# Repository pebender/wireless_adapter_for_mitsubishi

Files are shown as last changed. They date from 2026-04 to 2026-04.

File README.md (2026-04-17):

# A Wireless Adapter for a Mitsubishi Heat Pump Indoor Unit

This project is neither associated with nor endorsed by Mitsubishi Electric. By using this project, you may void your warranty or break your heat pump.

## The Wireless Adapter

The wireless adapter is a device for connecting an indoor unit of [our Mitsubishi Electric heat pump system](./docs/requirements.md#existing-system) to [our home automation system](./docs/background/automation.md). The wireless adapter is similar to [Mitsubishi Electric's PAC-USWHS002-WF-2 Wireless Interface 2](https://www.mitsubishipro.com/products/PAC-USWHS002-WF-2), except the wireless adapter is Open Source and doesn't depend on a cloud service.

The wireless adapter has three distinct parts

- the Open Source [hardware](./docs/hardware.md),
- the Open Source [enclosure](./docs/enclosure.md) and
- the Open Source [firmware](./docs/firmware.md).

### The Wireless Adapter Hardware

The [hardware](./docs/hardware.md) is likely both overly and poorly designed. Relative to many other people's designs, my design pays (more) attention to safety, including correct logic levels, safe power consumption and transient voltage suppression.

The hardware is a two-layer printed circuit board assembly (PCBA). I did the design and layout using the Open Source PCB design suite [KiCad](https://www.kicad.org). In addition, I did the step down power supply design using [Texas Instrument's WEBENCH&reg; Power Designer](https://webench.ti.com/power-designer/). I paid [JLCPCB](https://jlcpcb.com) to fabricate and assemble the hardware. I licensed the hardware design and layout under the [MIT license](./LICENSE.txt).

### The Wireless Adapter Enclosure

The [enclosure](./docs/enclosure.md) is likely overly conservative. I had no experience designing 3D printed enclosures, and I wanted to be sure the enclosure wasn't too fragile.

I did the enclosure design using the Open Source 3D parametric modeler [FreeCAD](https://www.freecad.org). I paid JLCPCB to 3D print the enclosure. I licensed the enclosure design under the MIT license.

### The Wireless Adapter Firmware

I contributed nothing to the [firmware](./docs/firmware.md). I built it from the Open Source [ESPHome](https://esphome.io) and the Open Source [mUART Project](https://muart-group.github.io)'s [mitsubishi_itp](https://github.com/muart-group/esphome-components) ESPHome component,

## The Motivation

I undertook this project because

- I needed a project,
- I wanted to learn what it takes to develop hardware today,
- I wanted to learn what it takes to develop enclosures, and
- I wasn't satisfied with our current solution for connecting the indoor units of our Mitsubishi Electric heat pump system to our home automation system. It depends on two [Honeywell THM6000R7001 RedLINK&reg; Internet Gateways](https://www.resideo.com/us/en/pro/products/air/thermostats/thermostat-accessories/redlinkr-internet-gateway-with-ethernet-cable-and-power-cord-thm6000r7001-u/) and the [Honeywell Home Total Connect Comfort](https://mytotalconnectcomfort.com) cloud. Because of its reliance on the RedLINK&reg; wireless protocol, it's relatively slow. In addition, because its reliance on the cloud it's relatively unreliable.

I wouldn't have undertaken this project had others not already done the work to connect their Mitsubishi Electric heat pumps to their home automation systems, including

- [Hadley Rich's hacking of his Mitsubishi heat pump)](https://nicegear.nz/blog/hacking-a-mitsubishi-heat-pump-air-conditioner/),
- [SwiCago's HeatPump software](https://github.com/SwiCago/HeatPump),
- [Geoff Davis (esphome-mitsubishiheatpump software)](https://github.com/geoffdavis/esphome-mitsubishiheatpump), and
- [the mUART project's software](https://muart-group.github.io).

In addition, I wouldn't have undertaken this project without the knowledge and confidence I gained as

- a high school student in [John McCollum](https://www.eetimes.com/john-mccollum-hs-teacher-taught-electronics-with-love/)'s electronics class at [Homestead High School](https://en.wikipedia.org/wiki/Homestead_High_School_(California)),
- a hardware intern at [NCR](https://www.ncr.com),
- a PhD student under [Jack Wolf](https://en.wikipedia.org/wiki/Jack_Wolf) at the [University of California San Diego (UCSD)](https://ucsd.edu), and
- a 20+ year employee at [Qualcomm](https://www.qualcomm.com).

Finally, I wouldn't have undertaken this project had an existing design contained

- a level shifter for the UART signals,
- a power module designed to meet the required efficiency and the EMI standards, and
- a reasonable level of Transient Voltage Suppression (TVS).

My [background](./docs/background.md) provides more insight into why I undertook this project.

## The Evolution

I didn't design the hardware and the enclosure as a unified project. Initially, I designed the hardware with the intent of using an off-the-shelf enclosure. So, I designed the hardware to fit in the off-the-shelf enclosure. However, I ran into problems mounting the hardware in the off-the-shelf enclosure as well as cutting the necessary openings in the off-the-shelf enclosure. So, I decided to make a custom enclosure. However, I already had the hardware fabricated and assembled. Therefore, I designed the enclosure around the existing hardware. Had I designed them together, both the hardware and the enclosure would have been different.

## References

[References](./docs/references.md)

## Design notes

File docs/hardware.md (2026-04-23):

# Wireless Adapter Hardware

I designed the wireless adapter hardware to meet [these requirements](./requirements.md).

The current design is the same circuit design and PCB layout as the design I had fabricated except

- I changed the value of capacitor C2 from 1μF to 0.1μF,
- I removed instances of different signals sharing one ground via from the PCB,
- I improved the USB data lines differential routing,
- I removed the wall mounting passthrough hole from the PCB,
- I added the name and revision to the PCB,
- I switched from a hierarchical schematic to a flat schematic, and
- I updated from KiCad 9.0.x to KiCad 10.0.x.

## Architecture

The high level block diagram below shows basic functions of the wireless adapter.

The [USB connector](./hardware/development.md#usb-connector) (along with the [reset and boot switches](./hardware/development.md#switches)) eases development.

The [IU connector](./hardware/connectors.md#the-wireless-adapters-iu-connector) and [WR connector](./hardware/connectors.md#the-wireless-adapters-wr-connector) connect to the indoor unit of a Mitsubishi Electric heat pump and the wireless receiver of a Mitsubishi Electric controller kit respectively

The [power multiplexer](./hardware/power.md#power-multiplexer) switches between the 5V power provided through the USB connector and the 12.7V power provided through the IU connector, with priority given to the IU connector's 12.7V power when present. This allows the USB connector to power the System on a Chip (SoC) during development.

The [voltage regulator](./hardware/power.md#33v-output-switching-voltage-regulator) converts the power from the output of the power multiplexer to the 3.3V needed to power the SoC as well as power the SoC side of the level shifter.

The [level shifter](./hardware/connectors.md#level-shifter) converts the UART signals between the 3.3V signals expected by the SoC and the 5V signals expected by the indoor unit (connected via the IU connector) and the wireless receiver (connected via the WR connector).

The SoC provides the Wi-Fi, Thread and Bluetooth LE interfaces to the indoor unit and the wireless receiver.

```mermaid
block
columns 7

USB["USB Connector"]
space:3
IU["IU Connector"]
space
WR["WR Connector"]

space:7

space:2
MULTIPLEXER["Power Multiplexer"]
space:1

block:LS["Level Shifter"]:3
    columns 3
    LS_IU_5V["TX/RX @5V"]
    LS_5V["5V"]
    LS_WR_5V["RX/TX @5V"]
    space:3
    LS_IU_3V3["TX/RX @3.3V"]
    LS_3V3["3.3V"]
    LS_WR_3V3["RX/TX @3.3V"]
end

space:7

space:2
REGULATOR["Voltage Regulator"]
space:4

space:7

block:SOC["System on a Chip"]:7
  columns 7
  USB_JTAG["USB Serial / JTAG"]
  space:1
  SOC_3V3["3.3V"]
  space:1
  UART_0["UART 0"]
  space:1
  UART_1["UART 1"]
  space:7
  CPU["CPU"]
  space:1
  WIFI["Wi-Fi"]
  space:1
  THREAD["Thread"]
  space:1
  BLE["Bluetooth LE"]
end

USB -- "5V" --> MULTIPLEXER
USB -- "D+/D-" --> USB_JTAG
USB_JTAG -- "D+/D-" --> USB

MULTIPLEXER --> REGULATOR
IU -- "12.7V/5V/GND" --> WR
IU -- "12.7V" --> MULTIPLEXER

IU -- "5V" --> LS_5V
IU -- "UART TX/RX" --> LS_IU_5V
LS_IU_5V -- "UART TX/RX" --> IU
WR -- "UART RX/TX" --> LS_WR_5V
LS_WR_5V -- "UART RX/TX" --> WR

LS_IU_5V --> LS_IU_3V3
LS_IU_3V3 --> LS_IU_5V
LS_WR_5V --> LS_WR_3V3
LS_WR_3V3 --> LS_WR_5V

REGULATOR -- "3.3V" --> LS_3V3
LS_IU_3V3 -- "UART TX/RX" --> UART_0
UART_0 -- "UART TX/RX" --> LS_IU_3V3
LS_WR_3V3 -- "UART RX/TX" --> UART_1
UART_1 -- "UART RX/TX" --> LS_WR_3V3

REGULATOR -- "3.3V" --> SOC_3V3
```

# Fabrication and Assembly

This is the first time that I have had a PCBA fabricated and assembled.

I chose [JLCPCB](https://jlcpcb.com) because they are a inexpensive, one-stop shop. They

- provide [parts](https://jlcpcb.com/parts),
- provide [PCB fabrication](https://jlcpcb.com/pcb-fabrication/fr4-pcb),
- provide [PCB assembly](https://jlcpcb.com/pcb-assembly),
- are reasonably priced, and
- are reasonably fast.

Because I chose JLCPCB, I made sure the parts I used are available from [JLCPCB parts](https://hlcpcb.com/parts). When possible, I chose resistors, capacitors and diodes that were available as basic or promotional extended parts because they are cheaper during PCB assembly. In addition, I chose parts that support surface mounted technology (SMT) rather than through hole technology (THT) because they are cheaper during assembly. The one exception is the JST S05B-PASK-2(LF)(SN) connector used for the IU connector and WR connector because through hole connectors tend to be more securely attached than surface mount connectors.

I made two versions of the PCBA. The first version was the test version. The second version was the "production" version. The first version worked but the USB-C connector was poorly placed. The second version was similar to the first version except the switches and ESD diodes were replaced with basic or promotional extended parts, the LEDs were removed, and the layout was changed.

## The Completed Design

### The Parts List

 The PCBA contains the parts

- System on a Chip: [Espressif ESP32-C6-WROOM-1-N8](./hardware/soc.md) (U1)
- Level Shifter: [Texas Instruments TXS0104EPW](./hardware/connectors.md#level-shifter) (U2)
- Power Multiplexer: [Texas Instruments TPS2121RUX](./hardware/power.md#power-multiplexer) (U7)
- Power Module: [Texas Instruments TPSM5601R5HRDA](./hardware/power.md#33v-output-switching-voltage-regulator) (U8)
- TVS Devices: [Texas Instruments TVS1400DRV](./hardware/connectors.md#power-pin-voltage-surge-protection) (U3, U5) and [Texas Instruments TVS0500DRV](./hardware/connectors.md#power-pin-voltage-surge-protection) (U4, U6)
- ESD Diodes: [R+O H5VL10B](./hardware/connectors.md#signal-pin-voltage-surge-protection) (D1-D7)
- USB Connector: [G-Switch GT-USB-7010ASV](./hardware/development.md#usb-connector) (J3)
- IU Connector: [JST S05B-PASK-2](./hardware/connectors.md#connectors) (J1)
- WR Connector: [JST S05B-PASK-2](./hardware/connectors.md#connectors) (J2)
- Switches: [XunPu TS-1088-AR02016](./hardware/development.md#switches) (S1, S2)
- Capacitors: [Samsung Electro-Mechanics capacitors](./hardware/passive.md#capacitors) (C1-C15)
- Resistors: [Uni-royal thick film 0402/0603/0805/1206/1210/1812/2010/2512 series resistors](./hardware/passive.md#resistors) (R1-R13)
- Inductor: [Murata DFE201610E-R47M=P2 inductor](./hardware/passive.md#inductors) (L1)

When selecting parts, I selected

- Espressif parts because I am familiar Espressif's development tools,
- Texas Instruments parts because I am familiar with Texas Instruments' design documentation and tools, and
- JLCPCB basic and promotional extended parts because they are less expensive during assembly.

### The Schematic

schematic

### The PCBA

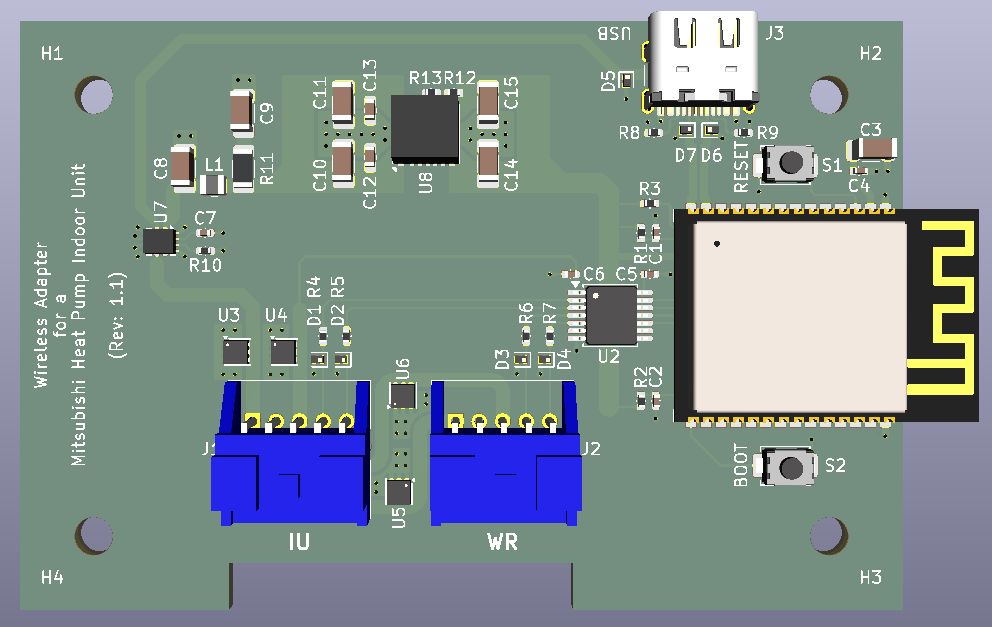
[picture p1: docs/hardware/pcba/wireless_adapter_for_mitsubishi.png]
PCBA


The completed PCBA is a two-layer, rigid PCBA. The bottom layer contains a ground plane. The top layer contains ground pours, the power pours, the power traces, the signal traces and the parts.

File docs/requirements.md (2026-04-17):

# Wireless Adapter Requirements

## Goal

The goal of this project is to create an Open Source wireless adapter for connecting the indoor units of our Mitsubishi Electric heat pump system to our [Home Assistant](https://www.home-assistant.io) centered home automation system without depending on the cloud.

## Existing System

Our Mitsubishi Electric heat pump system consists of eight indoor units

- MSZ-GL06NA-U1 (study),
- MSZ-GL09NA-U1 (office),
- MSZ-GL09NA-U1 (guest bedroom),
- MSZ-GL09NA-U1 (back bedroom),
- MSZ-GL15NA-U1 (family room),
- MSZ-GL18NA-U1 (kitchen),
- MSZ-GL18NA-U1 (living room),
- MSZ-GL18NA-U1 (master bedroom),

connected to three outdoor units

- MUZ-GL15NA-U1 (family room),
- MXZ-4C36NA2-U1 (kitchen, study, master bedroom), and
- MXZ-5C42NA2-U1 (living room, office, guest bedroom, back bedroom).

Each indoor unit is connected to a [Mitsubishi Electric MHK1 controller kit](https://www.mitsubishipro.com/products/MHK1), consisting of a MIFH1 wireless receiver and a MRCH1 remote controller.

In addition to being paired with its MRCH1 remote controller, the MIFH1 wireless receiver connected to each indoor unit is paired with one of two [Honeywell THM6000R7001 RedLINK&reg; Internet Gateways](https://www.resideo.com/us/en/pro/products/air/thermostats/thermostat-accessories/redlinkr-internet-gateway-with-ethernet-cable-and-power-cord-thm6000r7001-u/). The THM6000R7001 internet gateways enable control of the indoor units from our phones and our home automation system. Unfortunately, they have two shortcomings. First, they have a slow response time because the RedLINK&reg; wireless protocol between the THM6000R7001 internet gateway and the MIFH1 wireless receiver is slow. Second, they can be unreliable because all their traffic is sent through the [Honeywell Home Total Connect Comfort](https://mytotalconnectcomfort.com) cloud. It's the THM6000R7001 internet gateways that this project will replace.

## Top Level Requirements

### Freedom Requirements

1. The wireless adapter hardware design must be Open Source.
    - The hardware components (e.g. the SoC) need not be Open Source.
2. The wireless adapter enclosure design must be Open Source
3. The wireless adapter firmware must be Open Source.
    - This prevents the owner of the wireless adapter from being subject to the whims of the firmware provider.
4. The wireless adapter must not require a cloud.
    - This prevents the owner of the wireless adapter from being subject to the whims of the cloud provider. For example, I was burned by a Genie Aladdin Connect when they changed their cloud API effectively blocking Home Assistant from using the cloud API.
5. The wireless adapter development tools must be Open Source.
    - This makes it easier to view and modify the wireless adapter design because the development tools are available without monetary or other restrictions.

### Connected Hardware Requirements

1. The wireless adapter must support the indoor units
    - the Mitsubishi Electric MSZ-GL06NA-U1,
    - the Mitsubishi Electric MSZ-GL09NA-U1,
    - the Mitsubishi Electric MSZ-GL15NA-U1 and
    - the Mitsubishi Electric MSZ-GL18NA-U1.
2. The wireless adapter must support the MIFH1 wireless receiver.
3. The wireless adapter must support the MIFH2 wireless receiver (aka MIFH2 receiver).
4. The wireless adapter must allow normal operation of the Mitsubishi Electric MHK1 remote controller kit.
5. The wireless adapter must allow normal operation of the Mitsubishi Electric MHK2 remote controller kit.

### Radios

1. The wireless adapter must support a wireless connection using 2.4 [Wi-Fi&reg;](https://www.wi-fi.org).
    - ESPHome supports Wi-Fi.
    - Matter supports Wi-Fi.
2. The wireless adapter must support a wireless connection using [Thread&reg;](https://threadgroup.org) 1.4.
    - ESPHome supports Thread.
    - Matter supports Thread.
    - A Thread radio at each indoor unit should form a good backbone for a Thread network.
3. The wireless adapter must support [Bluetooth&reg;](https://www.bluetooth.com/) LE.
    - The Matter provisioning protocol relies on Bluetooth LE.

### Firmware

1. The wireless adapter hardware must support [ESPHome](https://esphome.io) firmware.
2. The wireless adapter hardware must support ESPHome over Wi-Fi.
3. The wireless adapter hardware must support ESPHome over Thread 1.4.
4. The wireless adapter hardware running ESPHome firmware must support the [Home Assistant](https://www.home-assistant.io) home automation system.
5. The wireless adapter hardware may support [Matter](https://csa-iot.org/all-solutions/matter/) firmware.

### Firmware Development

1. The wireless adapter must provide a USB-C connector.
    - The move has been toward the USB-C connector and away from other types of USB connectors.
2. The wireless adapter must support wireless adapter firmware download, debug and recovery over USB.
3. The wireless adapter must support being powered over USB.
4. The wireless adapter should provide transient voltage suppression (TVS) or electrostatic discharge (ESD) protection on the USB's VBUS, D+ and D- pins.

### IU Connector

1. The wireless adapter must provide a connector that is physically and electrically the same as the indoor unit's CN105 connector except that the UART RX and UART TX pins are reversed.
    - See [the IU connector](#the-iu-connector).
2. The wireless adapter must provide transient voltage suppression (TVS) for the connector's 12.7V and 5V pins.
3. The wireless adapter must provide electrostatic discharge (ESD) protection for the connector's UART RX and UART TX pins.
4. The wireless adapter must provide current limiting resistors for the connector's UART RX and UART TX pins.
5. The wireless adapter must control the indoor unit through a wired connection between connector to the indoor unit's CN105 connector.

### WR Connector

1. The wireless adapter must provide a connector that is physically and electrically the same as the indoor unit's CN105 connector.
    - See [the WR connector](#the-wr-connector).
2. The wireless adapter must provide transient voltage suppression (TVS) for the connector's 12.7V and 5V pins.
3. The wireless adapter must provide electrostatic discharge (ESD) protection for the connector's UART RX and UART TX pins.
4. The wireless adapter must provide current limiting resistors for the connectors UART RX and UART TX pins.

### Power

1. The wireless adapter must require no other power source than the indoor unit's CN105 connector.
2. The wireless adapter must be powered by the 12.7V pin of the indoor unit's CN105 connector.
    - See [Maximum Allowed Power Consumption](#maximum-allowed-power-consumption).
3. The wireless adapter must draw no more than 2W from the 12.7V pin of the indoor unit's CN105 connector.
    - See [Maximum Allowed Power Consumption](#maximum-allowed-power-consumption).
4. The wireless adapter may power the 5V side of the level shifter using the 5V pin of the indoor unit's CN105 connector.

## Maximum Allowed Power Consumption

I found no documentation covering the power supplied by the indoor unit's CN105 connector.

However, the wireless adapter is functionally the same as the [Mitsubishi Electric's PAC-USWHS002-WF-2 Wireless Interface 2](https://www.mitsubishipro.com/products/PAC-USWHS002-WF-2) except that the PAC-USWHS002-WF-2 requires a cloud and is not Open Source. Therefore, using the PAC-USWHS002-WF-2, I have been able to determine a power the wireless adapter can consume while still allowing my indoor unit to safely power the wireless adapter and the MIFH1/MIFH2 wireless receiver.

The [PAC-USWHS002-WF-2 Installation/Instruction Manual from 2021](https://s3.amazonaws.com/enter.mehvac.com/DAMRoot/Original/10006/PAC-USWHS002-WF-2_Install_Manual.pdf) states that the PAC-USWHS002-WF-2 consumes a maximum of 2W at 12.7V. So, a device that consumes no more than 2W from the CN105's 12.7V pin could be powered by any indoor unit compatible with the PAC-USWHS002-WF-2.

The [PAC-USWHS002-WF-2 Compatibility Submittal from 2021](https://s3.amazonaws.com/enter.mehvac.com/DAMRoot/Original/10009/M_Submittal_PAC-USWHS002-WF-2.pdf) states that simultaneous use of the PAC-USWHS002-WF-2 and the MIFH1/MIFH2 wireless receiver is only compatible with a subset of indoor units individually compatible with the PAC-USWHS002-WF-2 and the MIFH1/MIFH2 wireless receiver due to power requirements. My indoor units are compatible with simultaneous use of the PAC-USWHS002-WF-2 and the MIFH1 wireless receiver. Therefore, my indoor units could simultaneously power the MIFH1 wireless receiver and a device that consumes no more than 2W from the CN105 connector's 12.7V pin.

I have found no information showing that any of my indoor units could simultaneously power the wireless adapter and the MIFH1 wireless receiver were the wireless adapter to consume more than 2W from the CN105 connector's 12.7V pin. Therefore, the power requirement is that the device must consume no more then 2W of power from the CN105 connector's 12.7V pin.

## The WR Connector

[Airzone](https://www.airzonecontrol.com/) enables connection of both its [AZAI6WSCMEL Aidoo WiFi controller](https://www.airzonecontrol.com/na/en/support/technical-details/aidoo-wi-fi-mitsubishi-electric/) and a MIFH1/MIFH2 wireless receiver to connect to an indoor unit using its separate [AZX6ACCSPLMEL CN105 port splitter](https://www.airzonecontrol.com/na/en/support/technical-details/CN105-port-splitter-mitsubishi-electric/). However, [Mitsubishi Electric's PAC-USWHS002-WF-2 Wireless Interface 2](https://www.mitsubishipro.com/products/PAC-USWHS002-WF-2) integrates a port for connecting a MIFH1/MIFH2 wireless receiver rather than relying on a separate device. In addition, the [mUART Project](https://muart-group.github.io)'s [mitsubishi_itp](https://github.com/muart-group/esphome-components/tree/dev/components/mitsubishi_itp) ESPHome component expects the MIFH1/MIFH2 wireless receiver to connect to the same hardware on which it is running.

Therefore, the wireless adapter must provide a connector for connecting a MIFH1/MIFH2 wireless receiver.

Since both the MIFH1 wireless receiver and the MIFH2 wireless receiver come with a cable with a connector that is expected to be plugged into the indoor unit's CN105 connector, the wireless adapter must provide a connector that is physically and electrically the same as the indoor unit's CN105 connector, with the exceptions that there may be less power available on the 12.7V and 5V pins.

 Therefore, the wireless adapter must provide a connector that is physically and electrically the same as the indoor unit's CN105 connector.

## The IU Connector

The wireless adapters's indoor unit (IU) connector could be either the same as or different from the WR connector.

Advantages of the IR and WR connectors being the same include

- fewer component variants in the design, and
- pre-made PAP-05V-S cables are available.

Disadvantages of the IR and WR connectors being the same include

- installer could confuse the two connectors.

If the wireless adapter is connected to the indoor unit using a rollover cable (a.k.a. same direction cable), then the IU and WR connectors will both have 12.7V, GND and 5V on pins 1, 2 and 3 respectively, and the IU connector will have its UART RX and TX pins reversed relative to the WR connector.

This can be addressed either by using a cable that swaps the the UART RX and TX pins or by protecting the UART pins when RX is connected to RX and TX is connected to TX.

Protocol agnostic straight-through cables (a.k.a. reverse direction cables) and rollover cables are available for a wide variety of connectors. However, crossover cables (cables that reverse the communication protocols RX and TX pins) are only available for common protocols with normalized (standardized) connectors and pin-outs (e.g. cables for ethernet over twisted-pair), which this is not. In addition, the current-limiting resistors on the UART pins of both connectors would protect the wireless adapter, the indoor unit and the MIFH1/MIFH2 wireless receiver from potential damage caused by the UART RX and TX pins being crossed when the user confuses the connectors.

Both Mitsubishi Electric's PAC-USWHS002-WF-2 wireless interface 2 and Airzone's AZX6ACCSPLMEL CN105 port splitter use the same type of connector to connect both the indoor unit and MIFH1/MIFH2 wireless receiver. Both connect to the indoor unit using a rollover cable.

 Therefore, the wireless adapter must provide a connector that is physically and electrically the same as the indoor unit's CN105 connector except that the UART RX and UART TX pins are reversed.

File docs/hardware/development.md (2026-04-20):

# Development

The wireless adapter has circuitry specifically for development. The design for this circuitry follows the design of the [ESP32-C6-DevKitC-1](https://dl.espressif.com/dl/schematics/esp32-c6-devkitc-1-schematics_v1.4.pdf).

## Switches

The wireless adapter has a switch to initiate chip reset and a switch to select the boot method. For the switches, I chose the [XunPu TS-1088-AR02016](https://www.lcsc.com/datasheet/C720477.pdf) because

- they're compact,
- they're in the JLCPCB basic parts type so it's lower cost during PCB assembly.

I used an RC filter to debounce each switch. When the switch is open, the resistor pulls the output high. When the switch is closed, the switch pulls the output low. The time constant of the reset switch's RC filter is ~10x the time constant of the boot switch's RC filter so that on power up the boot switch has time to be pulled high before the reset switch is pulled high.

## USB Connector

The wireless adapter has a 16-pin USB 2.0 Type-C connector providing USB 2.0 connectivity to the ESP32-C6-WROOM-1-N8's USB data lines. The ESP32-C6 supports 12Mbps transfer rate and implements USB serial and JTAG controller. I chose a Type-C connector because the Type-C connector is compact and has become the dominant USB connector. Any 16-pin USB 2.0 Type-C connector should work. I selected the [G-Switch GT-USB-7010ASV](https://www.lcsc.com/datasheet/C2988369.pdf).

## Protection

The wireless adapter has 5V bidirectional ESD diodes on the USB VBUS, D+ and D- lines to provide [ESD protection](./connectors.md#signal-pin-voltage-surge-protection).

## Power Multiplexer

The wireless adapter [multiplexes the 12.7V from the IU connector and the 5V from the USB connector](./power.md#power-multiplexer) so that the wireless adapter remains powered when doing development without the wireless adapter being connected to the indoor unit.

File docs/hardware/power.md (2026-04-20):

# Power

## Overview

The power design uses

- a [Texas Instruments TPS2121RUX](https://www.ti.com/product/TPS2121) power multiplexer to select whether the wireless adapter is powered by the IU connector's 12.7V pin or the USB connector's VBUS pins with priority given to power from the IU connector's 12.7V pin when present,
- a [Texas Instruments TPSM5601R5HRDA](https://www.ti.com/product/TPSM5601R5H) switching power module to convert the multiplexed voltage to 3.3V,
- capacitors at the input and output of the TPSM5601R5HRDA to reduce output voltage ripple caused by the power module's switching nature and the load's variable current demand, and
- a filter before the input capacitors to reduce the conducted EMI caused by the power module's switching nature to a level that meets the CISPR 22 Class B requirements.

In addition, the power design uses power from the IU connector's 5V pin to power the 5V side of the operational connectors' level shifter.

## Power Multiplexer

In order to power the wireless adapter from the IU connector's 12.7V pin during normal operation and from the USB connector's VBUS pins during firmware development, there must be a way to safely and reliably arbitrate between the two potential power sources. To accomplish this, the design uses the [Texas Instruments TPS2121RUX](https://www.ti.com/product/TPS2121) power multiplexer to multiplex the 12.7V supply from the UI connector and the 5V supply from the USB connector so that the wireless adapter is powered by the 12.7V supply from the indoor unit during normal operation and by the 5V supply from the USB host during firmware development. The 12.7V supply from the UI connector takes priority over the 5 supply from the USB connector. This enables firmware development while connected to the indoor unit.

I chose the Texas Instruments TPS2121RUX power multiplexer because it handles up to a 24V input, which is more than the 19.3V limited to by the [surge protection](./connection.md#power-pin-voltage-surge-protection).

### Rejected Power Multiplexer Options

The design could have assumed that the IU connector and the USB connector would never be connected at the same time, which would have eliminated the need for the power multiplexer. However, that would put the indoor unit, the USB host and the wireless adapter at risk. In addition, it would make firmware more difficult Therefore, I did not take this approach.

The design could have used a mechanical solution such as a jumper or a switch to select the power source. However, jumpers can come loose and both jumpers and switches must be put in the correct position by the user. So, a mechanical solution is susceptible to user error. Therefore, I did not take this approach.

The design could have used Schottkey diodes for power ORing. However, the ~0.5V voltage drop across the diode translates to ~4% power loss when being powered by the 12.7V supply, which is significant when the ESP32-C6-WROOM-1 recommendation for a power supply of 1.65W (3.3V @ 500mA) and the device must draw no more than 2W from the 12.7V supply. Therefore, I did not take this approach.

The design could hae used discrete transistors and resistors for power ORing. As the Texas Instruments TPS2121RUX costs ~$1.00 in small quantities, the discrete solution would very likely be cheaper. However, the ASIC requires fewer components and is more likely to work correctly on the first try. Maybe in the next iteration, I will replace the TPS2121RUX with discrete transistors and resistors. But for this iteration, I did not take this approach.

The design could have done power ORing after conversion to 3.3V. Doing this would have allowed the use of the less expensive [Texas Instruments LM66200DRL](https://www.ti.com/product/LM66200). However, ORing after the conversion to 3.3V would have required separate step down converters for the UI connector's 12.7V supply and the USB connector's 5V supply. This would cut into the cost savings from being able to use the less expensive Texas Instruments LM66200DRL, and would have required more wireless adapter area. Therefore, I did not take this approach.

## Step Down Voltage Regulator

### Power Requirements

Per Section 1.3 of [ESP32-C6 Hardware Design Guidelines (dated 2026.03.03)](https://documentation.espressif.com/esp-hardware-design-guidelines/en/latest/esp32c6/esp-hardware-design-guidelines-en-master-esp32c6.pdf) the recommended power supply has a voltage of 3.3V and an output current of no less than 500mA.

Per Section 6.4 of [ESP32-C6-WROOM-1 & ESP32-C6-WROOM-1U Datasheet (version 1.4)](https://www.espressif.com/sites/default/files/documentation/esp32-c6-wroom-1_wroom-1u_datasheet_en.pdf), the maximum current required by the ESP32-C6-WROOM-1-N8 processor and radio is 382mA, which is needed when transmitting the IEEE 802.11b 1Mbps DSSS waveform at full power. This does not include any power required by any non-radio peripherals (e.g., the UARTs and their associated GPIOs) that might be in use. In addition, this does not include any power required by hardware other than the ESP32-C6-WROOM-1-N8 (e.g., the UART level shifter).

Based on information about the Mitsubishi Electric's PAC-USWHS002-WF-2 Wireless Interface 2, the wireless adapter [must not draw more than 2W from indoor unit's 12.7V supply](../requirements.md#maximum-allowed-power-consumption). Therefore, the step down converter that converts 12.7V to 3.3V must be at least 82.5% efficient to meet the 500mA requirement when the indoor unit is powering the wireless adapter.

I have found no information about the maximum power the wireless adapter can draw from the indoor unit's 5V supply.

### Power During Normal Operation

During normal operation, nothing is connected to the USB connector. Therefore, the wireless adapter is powered by the indoor unit through the wireless adapter's IU connector during normal operation.

#### 3.3V

The ESP32-C6-WROOM-1-N8 and the ESP32-C6-WROOM-1-N8 side of level shifter uses 3.3V. The ESP32-C6-WROOM-1-N8's radios use most of the power. 

From the PAC-USWHS002-WF-2's documentation, [I concluded that the PAC-USWHS002-WF-2 is powered by the indoor unit's 12.7V power source](../requirements.md#maximum-allowed-power-consumption). Therefore, I chose to power most of the wireless adapter from the indoor unit's 12.7V power source during normal operation.

From the PAC-USWHS002-WF-2's documentation, [I concluded that the PAC-USWHS002-WF-2 draws no more than 2W from the indoor unit's 12.7 power source](../requirements.md#maximum-allowed-power-consumption). From this, I concluded that it's safe for the wireless adapter to draw up to 2W from the indoor unit's 12.7 power source but it might not be safe to draw more. Therefore, the step down converter that converts 12.7V to 3.3V must be at least 82.5% efficient to meet the ESP32-C6 Hardware Design Guidelines' 500mA requirement.

Since a linear step down regulator that converts from 12.7V to 3.3V would be 26.0% efficient at best, the design uses a switching step down regulator for converting from 12.7V to 3.3V.

#### 5V

The indoor unit and wireless receiver side of the level shifter uses 5V.

Converting the 12.7V power source to both 3.3V and 5V would require more circuitry than just converting to 3.3V. One solution is to use an LM7805 to convert from 12.7V to 5V [as appears to be done in at least some indoor units](https://cuttlefishblacknet.wordpress.com/2019/05/). Another solution is to convert from 3.3V to 5V using a boost converter. The level shifting circuit requires relatively little power from either the 3.3V source of the 5V source. Therefore, the wireless adapter uses the 5V source from the indoor unit to power the 5V side of the level shifting circuitry.

### Power During Recovery

A failed over-the-air (OTA) firmware load could put the wireless adapter in a state where OTA firmware loading does not work. If this happens, then the end user should be able to load the wireless adapter's firmware through the USB connector. There is less risk of harm to the end user and the indoor unit, if the wireless adapter is disconnected from the indoor unit when loading firmware using the USB connector. Therefore, I designed the wireless adapter to be powered by either the IU connector or the USB connector.

Since the wireless adapter is not connected to the indoor unit during recovery, the level shifting circuitry does not require power. Therefore, while the USB connector provides power for the wireless adapter's 3.3V circuitry, it does not provide power to the 5V side of the level shifting circuitry.

### 3.3V Output Switching Voltage Regulator

The power multiplexer may feed the switching regulator from the USB connector's VBUS pins or from the IU connector's 12.7V pin.

The wireless adapter's USB connector is a USB 2.0 full speed (12Mbps), high power (1.5A @ 5V) connection. Per the USB 2.0 specification, the voltage on the supplied to the device must be at least 4.35V for low power devices and 4.75V for high power devices. Since all high power devices must be able to operate as low power devices, the switching regulator must operate normally with an input voltage as low as 4.35V.

I don't know the indoor unit's 12.7V source characteristics. However, it's voltage is unlikely to drop as low as the lower limit set by the USB connector. In addition, the Texas Instruments TPS2121RUX operates normally with input voltages up to 22V and survives transient input voltages up to 24V. Finally, the Texas Instruments TVS1400DRV I selected for TVS protection on the 12.7V IU and WR connector pins, has a maximum clamping voltage of 19.3V. Therefore, as long as the switching regulator operates normally with an input voltage as high as 22V and survives a transient input voltage as high as 24V, the Texas Instruments TPS2121RUX and not the switching regulator will be the limiting factor.

#### Selecting the Switching Voltage Regulator

Compared with linear regulators, switching regulators tend to generate more radiated and conducted electromagnetic interference (EMI) and tend to have greater output voltage ripple. And, improper wireless adapter layout can unnecessarily increase the switching regulator's EMI and output voltage ripple. Conversely, proper input and output filters can decrease the switching regulator's EMI and output voltage ripple.

Many companies provide switching regulator solutions with various levels of integration. I have never designed a power supply circuit. However, during my career, I have seen how hard it can be to get power supply designs right. As a result, I have a strong preference for solutions that

- are highly integrated,
- meet radiated EMI requirements without additional components,
- use shielded components,
- have detailed test results, and
- have tools for designing proper power supplies including the input capacitors, the output capacitors and the conducted EMI filter.

Finally, I have a preference for a solution that does not necessitate a wireless adapter that has more than two layers or components on both sides of the wireless adapter because each of these things can increase the cost of wireless adapter manufacture and assembly as well as limit where the wireless adapter can be manufactured and assembled.

After looking at the offerings from various companies, I settled on [power modules from Texas Instruments](https://www.ti.com/power-management/dcdc-power-modules/power-modules-integrated-inductor/overview.html). Texas Instruments provides good datasheets for their power modules, including recommendations for supporting passive components and recommendations for wireless adapter layout. In addition, they provide [WEBENCH&reg; Power Designer](https://webench.ti.com/power-designer/switching-regulator) to assist with choosing supporting components and designing input EMI filters. Finally, they provide various application notes that explain how components are chosen and EMI filters are designed.

After eliminating offerings that did not

- support the required input voltage range,
- support the output current range,
- achieve the necessary efficiency,
- meet radiated EMI requirements,
- use either shielded inductors or shielded packaging,
- recommend a wireless adapter layout with four-layer, and/or
- recommend a wireless adapter layout with components on both sides,

I settled on the [Texas Instruments TPSM5601R5HRDA](https://www.ti.com/product/TPSM5601R5H). It is in a family that includes

- TPSM560R6: 600mA output, 400kHz switching frequency,
- TPSM560R6H: 600mA output, 1MHz switching frequency,
- TPSM5601R5: 1.5A output, 400kHz switching frequency,
- TPSM5601R5H: 1.5A output, 1MHz switching frequency,
- TPSM5601R5S: 1.5A output, 400kHz switching frequency, spread spectrum, and
- TPSM5601R5HS: 1.5A output, 1MHz switching frequency, spread spectrum

Any one in the family meet the requirements. However, the TPSM5601R5HRDA has the best availability and price at JLCPCB. Since the 400kHz switching frequency versions appear to have somewhat higher efficiency and the spread spectrum versions should have better EMI characteristics, if availability and cost of other members of the family improve, then I may change the design to use one of the other parts in the family.

#### Choosing External Components

The [TPSM5601R5H datasheet](./references/parts/Texas_TPSM5601R5H.pdf), the [TPSM5601R5H evaluation wireless adapter](https://www.ti.com/tool/TPSM5601R5HEVM), and [WEBENCH&reg; Power Designer](https://webench.ti.com/power-designer/switching-regulator) provide recommended/suggested values for external components required by the TPSM5601R5H. Sometimes the values they suggest differ.

##### Choosing the Feedback Resistors

The TPSM5601R5HRDA needs a top feedback resistor and a bottom feedback resistor to set the output voltage. Section 8.3.1 of the TPSM5601R5HRDA datasheet provides an equation that relates the ratio of the two resistors to the desired output voltage, recommends the value of the top feedback resistor should 10kΩ, and recommends the value of the top feedback resistor should not exceed 1MΩ. Figure 8-1 of the TPSM5601R5HRDA evaluation wireless adapter shows that the evaluation wireless adapter uses a 10kΩ to feedback resistor. However, the design recommended by WEBENCH&reg; Power Designer uses a 100kΩ top feedback resistor.

I chose a top feedback resistor of 51kΩ and bottom feedback resistor of 22kΩ. I chose these values because

- their ratio yields an output voltage of 3.3V,
- the top feedback resistor is below the datasheet's maximum recommended value of 1MΩ,
- the values of the resistors are large enough that their current requirements do not noticeably reduce the current output at typical or high loads, and
- they are resistors that are in JLCPCB's basic parts tier: [51kΩ](https://jlcpcb.com/partdetail/26537-0402WGF5102TCE/C25794) and [22kΩ](https://jlcpcb.com/partdetail/26511-0402WGF2202TCE/C25768).

##### Choosing the Feedforward Capacitor

THe datasheet and the evaluation wireless adapter make no mention of a feedforward capacitor in parallel with the top feedback resistor. However, WEBENCH&reg; Power Designer recommends a 91pF feedforward capacitor.

I chose no feedforward capacitor because

- the datasheet does not mention a feedforward capacitor,
- the evaluation wireless adapter does not have a feedforward capacitor, and
- the WEBENCH&reg; Power Designer recommended capacitor value is not available in the JLCPCB basic tier.

In the future, I may

- take a closer look at [Optimizing Transient Response of Internally Compensated
DC-DC Converters With Feedforward Capacitor [Texas Instruments SLVA289B)](https://www.ti.com/lit/an/slva289b/slva289b.pdf),
and/or
- perform more simulations,

to decide whether or not the wireless adapter would benefit sufficiently from a feedforward capacitor.

##### Choosing the Output Capacitors

Section 8.3.3 of the TPSM5601R5H datasheet provides a graph of minimum output capacitance as a function of output voltage. According to this graph, the minimum output ceramic capacitance for a 3.3V output is approximately 80uF. The TPSM5601R5H evaluation wireless adapter follows the datasheet and has two 47μF ceramic output capacitors. Just like the TPSM5601R5H evaluation wireless adapter, the design recommended by WEBENCH&reg; Power Designer has two 47μF ceramic output capacitors.

Likewise, I chose two 47μF because

- they are the values recommended by the datasheet, the evaluation wireless adapter and WEBENCH&reg; Power Designer, and
- they are capacitors that are in JLCPCB's basic tier: [47μF](https://jlcpcb.com/partdetail/97327-CL31A476MPHNNNE/C96123).

##### Choosing Input Capacitors

Section 8.3.2 of the TPSM5601R5H datasheet states that "a minimum input capacitance of 9.4μF (2 × 4.7μF) of ceramic type" are required. The TPSM5601R5H evaluation wireless adapter follows the datasheet and has two 4.7μF ceramic input capacitors. However, the design recommended by WEBENCH&reg; Power Designer is one 4.7μF and two 22nF capacitors.

The TPSM5601R5H is designed for symmetric placement of input and output capacitors. Therefore, the single 4.7μF input capacitor recommended by WEBENCH&reg; Power Designer is not ideal. In addition, the 4.7μF capacitors available in JLCPCB's basic tier suffer a significant loss in capacitance at a DC bias of 12.7V.

If the WEBENCH&reg; suggested 4.7μF capacitor is replaced with two 2.2μF, then they can be placed symmetrically. In addition, [JLCPCB has a 2.2μF capacitor in the basic tier](https://jlcpcb.com/partdetail/51263-CL31B225KBHNNNE/C50254) that does not suffer significant loss in capacitance at a DC bias of 12.7V.

For input capacitors, I chose two 22nF capacitors and two 2.2μF because

- it is in line with the values suggested by WEBENCH&reg; Power Designer, and
- JLCPCB's basic tier has a [22nF](https://jlcpcb.com/partdetail/21834-CL10B223KB8NNNC/C21122)
capacitor and a [2.2μF](https://jlcpcb.com/partdetail/51263-CL31B225KBHNNNE/C50254)

If 9.4μF input capacitance is needed, then two additional 2.2μF would close the gap. However, because the EMI filter adds to the input capacitance, the two additional 2.2μF capacitors may not be needed.

#### Choosing the EMI Filter Design and Components

Switching regulators generate electromagnetic interference (EMI). Care must be taken in the design to minimize EMI. The Texas Instruments' TPSM5601R5HRDA was designed to meet the requirements of CISPR 22 Class B (and EN 55022 Class B) for radiated emissions. However, it does not meet CISPR 22 Class B conducted emissions without an external filter.

Thankfully, [Texas Instruments WEBENCH&reg; Power Designer](https://webench.ti.com/power-designer/switching-regulator) to help with picking the external components needed by the TPSM5601R5H, including the components for the input filter needed to meet CISPR 22 Class B conducted emissions requirements. In addition, Texas Instruments provides application notes and datasheet to help with understanding the various EMI requires as well as to help with understanding and designing the EMI filter,

The components and area required by the EMI filter add cost to the wireless adapter. In addition, it's likely the wireless adapter would not cause problems were it built without the EMI filter. Many switching regulator modules sold to hobbyists like myself don't have a filter to meet CISPR 22 Class B conducted emissions requirements, and I suspect many of them do not meet either CISPR 22 Class B conducted emissions requirements or CISPR 22 Class B radiated emissions requirements. However, I would rather be safe than sorry.

For the EMI filter, I accepted the WEBENCH&reg; design but

- I changed the components from the recommended by WEBENCH&reg; to components available from JLCPCB, and
- I changed the inductor to a shielded inductor.

The filter inductor and dampening capacitor were in the WEBENCH&reg; list of alternate components. The filter capacitor and dampening resistor were not in the WEBENCH&reg; list of alternate components. However, there are similar components on the list that are JLCPCB basic components.

Just as I chose a power module with a shielded inductor because shielding the inductor helps minimize radiated EMI, I chose a shielded filter inductor.

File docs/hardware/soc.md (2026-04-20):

# The System on a Chip

I chose a System on a Chip (SoC) from the Espressif ESP32 family because

- the ESP32 family contains SoCs that meet the requirements,
- I am familiar with the ESP32 family,
- [ESPHome](https://esphome.io) has good support for the ESP32 family, and
- the ESP32 family contains pre-certified SoC modules.

I chose the [ESP32-C6-WROOM-1-N8](https://documentation.espressif.com/esp32-c6-wroom-1_wroom-1u_datasheet_en.pdf) because

- it has two UARTs,
- it has integrated radios,
- it has an integrated antenna,
- it supports 2.4GHz Wi-Fi 6,
- it supports [Thread 1.4](https://www.espressif.com/en/news/ESP32-C6_Thread_1.4_Certificate),
- it supports Bluetooth LE 5.3, and
- it appears to meet the power budget according to the [ESP32-C6 Hardware Design Guidelines](https://docs.espressif.com/projects/esp-hardware-design-guidelines/en/latest/esp32c6/esp-hardware-design-guidelines-en-master-esp32c6.pdf) (Section 1.3.2 recommends a 500mA power supply)

I would have chosen the [ESP32-C5-WROOM-1-N8](https://documentation.espressif.com/esp32-c5-wroom-1_wroom-1u_datasheet_en.pdf) because in addition what is supported by the ESP32-C6-WROOM-1-N8,

- it supports 5GHz Wi-Fi 6, and
- it supports Bluetooth LE 6.0.

Unfortunately, it doesn't appear to meet the power budget according to the [ESP32-C5 Hardware Design Guidelines](https://docs.espressif.com/projects/esp-hardware-design-guidelines/en/latest/esp32c5/esp-hardware-design-guidelines-en-master-esp32c5.pdf) (Section 1.3.2 recommends a 600mA power supply).

Both the ESP32-C6-WROOM-1-N8 and the ESP32-C5-WROOM-1-N8 are overkill for a Wi-Fi only device. However, in addition to running ESPhome and connecting over Wi-Fi, I wanted to experiment with

- running ESPHome and connecting over Thread
- running Matter and connecting over Wi-Fi, and
- running Matter and connecting over Thread.

As a result, I needed the Thread and Bluetooth LE radios and the extra flash memory reduces the need to optimize the firmware.

I am particularly interested in Thread because I believe that a Thread radio at every indoor unit would create a solid backbone for a Thread network. Once I have a solid backbone, I can begin to move devices from Wi-Fi to Thread.

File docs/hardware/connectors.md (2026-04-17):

# Operational Connectors

## Connectors

The wireless adapter has two operational connectors

- the IU connector and
- the WR connector.

The IU connector connects the wireless adapter to the Mitsubishi Electric heat pump's indoor unit. The WR connector connects the wireless adapter to the Mitsubishi Electric MIFH1/MIFH2 wireless receiver. So, there are four connectors involved

- the indoor unit's CN105 connector, and
- the wireless adapter's WR connector.
- the wireless adapter's IU connector, and
- the wireless receiver's cable connector.

These connectors can be divided into two classes

- Output connectors:
    - the indoor unit's CN105 connector, and
    - the wireless adapter's WR connector.
- Input connectors:
    - the wireless adapter's IU connector, and
    - wireless receiver's cable connector.

where output connectors source power and input connectors sync power.

Because the indoor unit's CN105 connector is a 5-pin, male, [JST PA family](https://www.jst-mfg.com/product/pdf/eng/ePA-F.pdf) connectors, all four connectors are 5-pin [JST PA family](https://www.jst-mfg.com/product/pdf/eng/ePA-F.pdf) connectors.

All four connectors have the same pinout except for the pin direction

| Pin Number | Pin Function | Indoor Unit  | IU | WR | Wireless Receiver
| --- | --- | --- | ----- | --- | ---
| 1 | 12.7V | Output | Input | Output | Input
| 2 | GND | Output | Input | Output | Input
| 3 | 5V | Output | Input | Output | Input
| 4 | UART | TX | RX | TX | RX
| 5 | UART | RX | TX | RX | TX

### The Wireless Adapter's IU Connector

I chose the [JST S05B-PASK-2(LF)(SN)](https://www.jst-mfg.com/product/pdf/eng/ePA-F.pdf) connector because it's a through hole device rather than a surface mount device. In general, through hole devices attach more securely than surface mount devices, which can be important with connectors.

A cable with a [JST PAP-05V-S](https://www.jst-mfg.com/product/pdf/eng/ePA-F.pdf) housing at each end connects between the indoor unit's CN105 connector and the wireless adapter's IU connector.

Essentially, the wireless adapter's IU connector along with the cable looks like the MIFH1/MIFH2 wireless receiver's cable connector to the indoor unit.

### The Wireless Adapter's WR Connector

I chose the [JST S05B-PASK-2(LF)(SN)](https://www.jst-mfg.com/product/pdf/eng/ePA-F.pdf) connector because it's a through hole device rather than a surface mount device. In general, through hole devices attach more securely than surface mount devices, which can be important with connectors.

Essentially, the wireless adapter's WR connector looks like the indoor unit's CN105 connector to the MIFH1/MIFH2 wireless receiver's cable connector.

## Connectivity

This diagram shows the connectivity. The IU connector and WR connector are part of the wireless adapter but are shown as separate because it is helpful in showing the difference between how the power pins (12.7V, GND and 5V) and signal pins (UART TX and UART RX) are routed. The level shifter is part of the wireless adapter but is shown as separate because it is helpful in showing the powering of and signal flow through the level shifter.

```mermaid
sequenceDiagram
    participant IU as Indoor Unit (CN105)
    participant IUC as IU Connector
    participant LS1 as Level Shifter
    participant WA as Wireless Adapter
    participant LS2 as Level Shifter
    participant WRC as WR Connector
    participant WR as Wireless Receiver
    Note over IU,WR: Pin 1
    IU->> IUC: 12.7V
    IUC->> WA: 12.7V
    IUC->> WRC: 12.7V
    WRC->> WR: 12.7V
    Note over IU,WR: Pin 2
    IU->> IUC:  GND
    IUC->> LS1: GND
    IUC->> WA: GND
    IUC->> LS2: GND
    IUC->> WRC: GND
    WRC->> WR: GND
    Note over IU,WR: Pin 3
    IU->> IUC: 5V
    IUC->> LS1: 5V
    IUC->> LS2: 5V
    IUC->> WRC: 5V
    WRC->> WR: 5V
    Note over IU,WR: Pin 4
    IU->> IUC: UART TX
    IUC->> LS1: UART RX
    LS1->> WA: UART RX (GPIO21)
    WA->> LS2: UART TX (GPIO20)
    LS2->> WRC: UART TX
    WRC->> WR: UART RX
    Note over IU,WR: Pin 5
    WR->> WRC: UART TX
    WRC->> LS2: UART RX
    LS2->> WA: UART RX (GPIO18)
    WA->> LS1: UART TX (GPIO19)
    LS1->> IUC: UART TX
    IUC->> IU: UART RX
    
```

## Power Pins

The 12.7V, GND and 5V are wired directly from the indoor unit to the wireless receiver. In addition, they are wired directly from the indoor unit to the wireless adapter. In particular, the 5V powers the level shifter's 5V rail, and the 12.7V powers the rest of the wireless adapter.

### Power Pin Voltage Surge Protection

Because of this direct wiring, voltage surges on a WR connector's power pin can travel to the IR connector's corresponding power pin and damage the indoor unit. Likewise, voltage surges on the IR connector's power pin can travel to the corresponding WR connector's power pin and damage the wireless receiver. Therefore, it's important to maximize protection against voltage surges on the power pins. So, I chose the most conservative surge protection devices I could find, which are the [Texas Instruments flat-clamp surge protection devices](https://www.ti.com/lit/wp/slyy127/slyy127.pdf). The 12.7V power pins on the IU and WR connectors rely on the [Texas Instruments TVS1400](https://www.ti.com/product/TVS1400) to clamp the voltage below 19.3V. The 5V pins on the IU and WR connectors rely on the [Texas Instruments TVS0500](https://www.ti.com/product/TVS0500) to clamp the voltage below 9.5V.

### Power Trace Protection

The JST PA family of connectors support up to 3A per pin. In addition, [it appears that at least some indoor units](https://cuttlefishblacknet.wordpress.com/2019/05/) have a 3A fuse on the 12.7V power supply. While I don't expect the indoor unit will supply 3A or the wireless receiver will draw 3A, I have found nothing to show that they couldn't. Therefore, I chose 1.2mm wide power traces between the IU and WR connectors. This results in a 12.5&deg;C temperature rise at 3A. Wider traces would have resulted in a lower temperature rise but would have resulted in a less compact layout for a situation that is unlikely to occur.

## Signal Pins

The indoor unit's UART signals are wired to the wireless adapter, and the wireless receiver's UART signals are wired to the wireless adapter. This allows the wireless adapter to manipulate the indoor unit's and wireless receiver's UART signals. Essentially, the wireless adapter acts as a man-in-the-middle.

### Level Shifter

For their UART signaling, the indoor unit and the wireless receiver use 5V logic. However, the [SoC](./soc.md) uses 3.3V logic. As a result, for the UART signals to be most reliable, the wireless adapter needs a level shifter to convert between the 5V logic and the 3.3V logic.

There are many different level shifters both discrete and integrated. I chose the [Texas Instruments TXS0104EPW](https://www.ti.com/product/TXS0104E) because

- it doesn't require sequencing of the two power rails, which makes it possible to apply the 3.3V rail when there is no 5V rail,
- it has auto-direction support, which simplifies routing, and
- it has a wide package, which makes it possible to run power and signal traces under the package.

Not requiring sequencing of the two power rails means that the 5V rail can be floating while the 3.3V rail is powered, which is what happens when doing development while the wireless adapter is disconnected from the indoor unit. Not requiring sequencing of the two power rails means that the 5V rail can be powered just before the 3.3V rail, which is what happens when the wireless adapter is connected to the indoor unit and the indoor unit is powered up.

The simplified routing afforded by the auto-direction support and the wide package made it possible to use a 2-layer PCB with the top layer being power and signalling and the bottom layer being a ground plane.

### Signal Pin Voltage Surge Protection

I chose to protect the UART RX and UART TX signal pins with traditional 5V bi-direction ESD protection diodes. Specifically, I chose [R+O H5VL10B](https://www.lcsc.com/datasheet/C7420372.pdf) ESD protection diodes. I chose these ESD protection diodes because

- the signal pins do not require the same protection as the power pins because the signal pins don't connect to another connector from which they might pick up a power surge,
- the diode is equivalent to the one used to protect the Espressif's [ESP32-C6-DevKitC-1](https://dl.espressif.com/dl/schematics/esp32-c6-devkitc-1-schematics_v1.4.pdf)'s USB-C VBUS, D+ and D- pins,
- the diode relatively small,
- the diode is available as a promotional extended part from JLCPCB so they are cheaper during PCB assembly.

### Series Resistor

There are two potential problems that can be addressed by putting a series resister between the level shifter and the connector.

First, it's possible to connect the indoor unit's connector to the WR connector and to connect the wireless receiver's connector to the IU connector. If this happens, then a the indoor unit's UART TX signal will be connected to a WR connector's UART TX signal and the wireless receiver's UART TX will be connected to the IU connector's UART TX signal. This can result in excessive current draw. This excessive current can be reduced or eliminated by adding an appropriately valued series resister n the UART signal line between the level shifter and the connector.

Second, the long cables from the indoor unit and the wireless receiver can result in signal ringing on signal edge transitions. This may be made worse by the level shifter as it contains circuitry to sharpen signal edge transitions. This ringing can be reduced or eliminated by adding an appropriately valued series resistor on the UART signal line between the level shifter and the connector.

I chose a 470&ohm; resister. This limits the current to ~10mA. I don't know whether the value is reasonable for reducing/eliminating ringing without slowing the transition too much.

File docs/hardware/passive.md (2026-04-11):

# Passive Components

## Resistors

I chose [Uni-royal thick film 0402/0603/0805/1206/1210/1812/2010/2512 series resistors](https://www.uni-royal.cn/en/product.php?id=19) because

- they're in the JLCPCB basic parts type so it's lower cost during PCB assembly.

## Capacitors

I chose [Samsung Electro-Mechanics Multilayer Ceramic Capacitors (MLCC)](https://www.samsungsem.com/global/product/passive-component/mlcc.do) because

- they're in the JLCPCB basic parts type so it's lower cost during PCB assembly. 

## Inductors

I chose the [Murata DFE201610E-R47M=P2](https://pim.murata.com/en-us/pim/details/?productCategoryId=inductor&partNum=DFE201610E-R47M%23) because

- it was recommended by WEBENCH&reg; Power Designer, and 
- their were no equivalent ones in JLCPCB basic or promotional extended parts type.

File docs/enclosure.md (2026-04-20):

# Wireless Adapter Enclosure

The current design is the same as the design I had fabricated except

- I updated from FreeCAD 1.0.x to FreeCAD 1.1.x, and
- I updated the PCBA STEP file to match the updated PCB.

## Design

I took a conservative approach to the design. The design has a top and bottom. The bottom has four holes for mounting the enclosure to the wall using drywall anchors. The bottom has four risers with M3 threaded holes for mounting the PCBA to the bottom. The PCBA is attached to the risers using standoffs so that top can be attached to the bottom using four M3 screws that go through the top and screw into the standoffs.

I chose to print using an SLA (resin) printer rather than an FDM (plastic) printer because

- the printing cost of SLA is less than printing cost of FDM at JLCPCB, and
- the finish of SLA is smoother than the finish of FDM.

### PCBA Mounting Holes

The bottom has four risers for attaching the PCBA to the bottom. Each riser has an M3 threaded hole. These four M3 threaded holes align with the four M3 holes in the PCBA.

Because the enclosure is made from resin not plastic, methods for adding strong M3 threaded holes that require melting the enclosure won't work.

I tried printing each riser with a threaded hole to receive an M4 to M3 thread repair insert. It turned out it didn't work because the SLA printer could not reliably print M4 threads. So, I tried three different methods for creating strong M3 threaded holes.

1. print each riser with a threaded hole to receive a 10mm long M6 to M3 thread repair insert ("bottom_T" in the FreeCAD design),
2. print each riser with a threaded hole to receive a 10mm long M6 to M3 thread repair insert and a hole to receive an anchor screw from the underside ("bottom_TWA" in the FreeCAD design), and
3. print each riser with a hexagonal hole to receive a 10mm long M3 hex coupling nuts and a hole to receive an anchor screw from the underside ("bottom_HWA" in the FreeCAD design).

The 10mm long M6 to M3 thread repair insert are standardized because they are essentially a M6 screw. I used the [HARFINGTON 10mm long M6 to M3 thread repair insert](https://www.amazon.com/dp/B0FDB66YRK). Unfortunately, the 10mm long M3 hex coupling is not standardized because its outer diameter is manufacturer dependent. I designed the riser hexagonal hole around the [uxcell 10mm long M3 hex coupling nut](https://www.amazon.com/dp/B09MWGV53L). For anchor screws, I used the [uxcell 8mm long flat countersunk head, hex drive M3 screws](https://www.amazon.com/dp/B07WJLFW2W).

To add extra strength, I thought I could add thick viscosity CA glue:

- for (1), I thought I could add glue to the M6 threads
- for (2), I thought I could add glue to the M6 threads and to the M3 threads of the anchor screw, and
- for (3), I thought I could add glue to the outside of the M3 hex coupling nuts and to the M3 threads of the anchor screw.

However, adding glue to (1) proved problematic. Glue got into some of the M3 threads, which made it difficult or impossible to screw in an M3 screw. Perhaps I could have avoided this had I put an M3 screw in the thread repair insert while screwing in the glue-coated thread repair insert. I tried to force the screw in hopes it would clear the glue. Instead, when I tried to remove the forced screw, I removed the thread repair insert. I discovered that the tight fit of the M6 threads had forced the glue out of the threads, making the glue useless. So, I abandon the idea of gluing in the thread repair inserts and the anchor screws.

Since I destroyed too many of (1), I had to use either (2) or (3). Since I have an affinity for the thread repair inserts, I used (2).

### Top and Bottom Attachment

I didn't attempt to design the top and bottom to snap together because I didn't know how to design a snap mechanism that's flexible enough to snap together but not so flexible as to break. Instead, I chose to use screws to hold the top and bottom together. Because of restrictions imposed by my different indoor unit locations, using a single design necessitated that the screw(s) be on top of the top rather than the sides of the top and that the top lift straight off the bottom. Therefore, I attached the PCBA to the bottom using four M3 standoffs and attached the top to the bottom by using using M3 screws through the top into the standoffs. The standoffs are 10mm long. The screws are 15mm long, have flat countersunk heads, and are the same color as the top. As a result, the screws blend in with the top reasonably well. The standoffs are from [JUNCHEN assorted M3 standoffs and spacers](https://www.amazon.com/dp/B0B2MPSH6T). The screws are from [Glarks assorted flat countersunk heads, phillips drive M3 screws](https://www.amazon.com/dp/B0DLZTHS4R).

### Antenna Keep-out

Per section 1.4.7 of [ESP32-C6 Hardware Design Guidelines](https://documentation.espressif.com/esp-hardware-design-guidelines/en/latest/esp32c6/esp-hardware-design-guidelines-en-master-esp32c6.pdf), the antenna should have a keep-out of 15mm. To help ensure the keep-out, the x direction and y direction keep-outs are inside the enclosure. The z direction keep-out is not completely inside the enclosure. However, there is unlikely to be metal in the z direction as the z-direction is into the wall and into the room.

## Manufacture

This is the first time that I have had an enclosure 3D printed.

I chose [JLCPCB](https://jlcpcb.com) because they

- Are reasonably priced, and
- Are timely.

I made two runs of the enclosure. The first run was a test version. The second run contained the "production" version. The first version worked except for the M4 to M3 thread repair inserts. The second run replaced the M4 to M3 thread repair inserts with three options: M6 to M3 thread repair inserts, M6 to M3 thread repair inserts and anchor screws, and M3 hex coupling nuts and anchor screws. Since the three bottom versions in the second run shared the same top and the top was more expensive than the bottom, it made sense to try multiple methods for creating M3 holes.

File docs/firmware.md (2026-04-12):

# Wireless Adapter Firmware

## ESPHome Firmware

The ESPHome firmware is built using [ESPHome](https://esphome.io) and [mUART Project](https://muart-group.github.io)'s [mitsubishi_itp](https://github.com/muart-group/esphome-components/tree/dev/components/mitsubishi_itp)  ESPHome component.

[example.yaml](../esphome/config/example.yaml) is a basic ESPhome configuration file for running ESPHome and mitsubishi_itp on the wireless adapter.

## Matter Firmware

The Matter firmware will be built using [esp-idf](https://docs.espressif.com/projects/esp-idf/en/stable/esp32/index.html) and [esp-matter](https://docs.espressif.com/projects/esp-matter/en/latest/esp32/index.html).

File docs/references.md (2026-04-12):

# References

- [Home Assistant](https://www.home-assistant.io)
  - [Thread integration](https://www.home-assistant.io/integrations/thread/)
  - [ESPHome integration](https://www.home-assistant.io/integrations/esphome)
  - [Matter integration](https://www.home-assistant.io/integrations/matter/)
- [ESPHome](https://esphome.io)
  - [mUART Project](https://muart-group.github.io)'s [mitsubishi_itp](https://github.com/muart-group/esphome-components/tree/dev/components/mitsubishi_itp)  ESPHome component
- [Matter](https://csa-iot.org/all-solutions/matter/)
  - [esp-idf](https://docs.espressif.com/projects/esp-idf/en/stable/esp32/index.html)
  - [esp-matter](https://docs.espressif.com/projects/esp-matter/en/latest/esp32/index.html)
- [Mitsubishi Electric](https://www.mitsubishicomfort.com)
  - [https://www.mitsubishipro.com](https://www.mitsubishipro.com)
  - [MSZ-GL**NA Indoor Unit](https://www.mitsubishipro.com/catalog/retired?q=MSZ-GL)
    - [Service Manual](https://s3.amazonaws.com/enter.mehvac.com/DAMRoot/Original/10006/M_MSZ-MSY-GL06-24NA_SERVICE_OBH732D.pdf)
    - [Parts Catalog](https://s3.amazonaws.com/enter.mehvac.com/DAMRoot/Original/10006/M_MSZ-MSY-GL06-24NA_Parts_OBB732E.pdf)
  - [MHK1 Controller Kit](https://www.mitsubishipro.com/products/MHK1)
    - [MHK1 Installation Manual](https://s3.amazonaws.com/enter.mehvac.com/DAMRoot/Original/10004/Mr_Slim_Series_MHK1_Central_Remote_Controller_Install_12-10.pdf)
    - [MRCH1 Operation Manual](https://s3.amazonaws.com/enter.mehvac.com/DAMRoot/Original/10006/Mr_Slim_Series_MHK1_Central_Remote_Controller_Operation_Manual.pdf)
  - [MHK2 Controller Kit](https://www.mitsubishipro.com/products/MHK2)
    - [MHK2 Installation Manual](https://s3.us-east-1.amazonaws.com/enter.mehvac.com/DAMRoot/Original/10009/MHK2_Installation_Manual_2025_Update.pdf)
    - [MRCH2 Operation Manual](https://s3.amazonaws.com/enter.mehvac.com/DAMRoot/Original/10009/MHK2_Operation-Manual_33-00447EFS_B.pdf)
  - [PAC-USWHS002-WF-2 Wireless Interface 2](https://www.mitsubishipro.com/products/PAC-USWHS002-WF-2)
    - [Installation Manual](https://s3.amazonaws.com/enter.mehvac.com/DAMRoot/Original/10006/PAC-USWHS002-WF-2_Install_Manual.pdf)
    - [Indoor Unit, MHK1/MHK2 and PAC-USWHS002-WF-2 Compatibility](https://s3.amazonaws.com/enter.mehvac.com/DAMRoot/Original/10009/M_Submittal_PAC-USWHS002-WF-2.pdf)
- Honeywell
  - [THM6000R7001 RedLINK&reg; Internet Gateway](https://www.resideo.com/us/en/pro/products/air/thermostats/thermostat-accessories/redlinkr-internet-gateway-with-ethernet-cable-and-power-cord-thm6000r7001-u/)
  - [Honeywell Home Total Connect Comfort](https://mytotalconnectcomfort.com) cloud
- [Espressif](https://www.espressif.com)
  - ESP32-C5-WROOM-1
    - [ESP32-C5 Hardware Reference](https://docs.espressif.com/projects/esp-idf/en/stable/esp32c5/hw-reference/index.html)
    - [ESP32-C5 Datasheet (Version 1.1)](https://documentation.espressif.com/esp32-c5_datasheet_en.pdf)
    - [ESP32-C5 Technical Reference Manual (Version 1.0)](https://documentation.espressif.com/esp32-c5_technical_reference_manual_en.pdf)
    - [ESP32-C5 Hardware Design Guidelines (March 27, 2026)](https://docs.espressif.com/projects/esp-hardware-design-guidelines/en/latest/esp32c5/esp-hardware-design-guidelines-en-master-esp32c5.pdf)
    - [ESP32-C5-WROOM-1 & ESP32-C5-WROOM-1U Datasheet (Version 1.1)](https://documentation.espressif.com/esp32-c5-wroom-1_wroom-1u_datasheet_en.pdf)
    - [ESP32-C5-DevKitC-1 schematic (Version 1.2)](https://dl.espressif.com/dl/schematics/SCH_ESP32-C5-DevkitC-1_V1.2_20250211.pdf)
  - ESP32-C6-WROOM-1
    - [ESP32-C6 Hardware Reference](https://docs.espressif.com/projects/esp-idf/en/stable/esp32c6/hw-reference/index.html)
    - [ESP32-C6 Datasheet (Version 1.5)](https://documentation.espressif.com/esp32-c6_datasheet_en.pdf)
    - [ESP32-C6 Technical Reference Manual (Version 1.2)](https://documentation.espressif.com/esp32-c6_technical_reference_manual_en.pdf)
    - [ESP32-C6 Hardware Design Guidelines (March 03, 2026)](https://documentation.espressif.com/esp-hardware-design-guidelines/en/latest/esp32c6/esp-hardware-design-guidelines-en-master-esp32c6.pdf)
    - [ESP32-C6-WROOM-1 & ESP32-C6-WROOM-1U Datasheet (Version 1.4)](https://documentation.espressif.com/esp32-c6-wroom-1_wroom-1u_datasheet_en.pdf)
    - [ESP32-C6-DevKitC-1 schematic (Version 1.4)](https://dl.espressif.com/dl/schematics/esp32-c6-devkitc-1-schematics_v1.4.pdf)
- [Texas Instruments (TI)](https://www.ti.com/)
  - [WEBENCH&reg; Power Designer](https://webench.ti.com/power-designer/)
  - [flat-clamp surge protection](https://www.ti.com/lit/wp/slyy127/slyy127.pdf)
    - [TVS0500DRV](https://www.ti.com/product/TVS0500) 5V flat-clamp surge protection device
    - [TVS1400DRV](https://www.ti.com/product/TVS1400) 14V flat-clamp surge protection device
  - [TXS0104EPW](https://www.ti.com/product/TXS0104E) 4-bit bidirectional voltage-level translator
  - [TPS2121RUX](https://www.ti.com/product/TPS2121) 2.8V to 22V priority power mux with seamless switchover
  - [TPSM5601R5HRDA](https://www.ti.com/product/TPSM5601R5H) 60V input, 1V to 16V output, 1.5A power module
- R+O
  - [H5VL10B](https://www.lcsc.com/datasheet/C7420372.pdf) ESD protection diode
- XunPu
  - [TS-1088-AR02016](https://www.lcsc.com/datasheet/C720477.pdf) 160gf 2mm x 4mm x 3mm tactile SPST switch
- JST
  - [S05B-PASK-2(LF)(SN)](https://www.jst-mfg.com/product/pdf/eng/ePA-F.pdf) 5-pin, 2mm pitch connector
- G-Switch
  - [GT-USB-7010ASV](https://www.lcsc.com/datasheet/C2988369.pdf) USB 2.0, type-C, 16-pin connector
- Murata
  - [DFE201610E-R47M=P2](https://pim.murata.com/en-us/pim/details/?productCategoryId=inductor&partNum=DFE201610E-R47M%23)
- Samsung Electro-Mechanics 
  - [Multilayer Ceramic Capacitors (MLCC)](https://www.samsungsem.com/global/product/passive-component/mlcc.do)
- Uni-royal
  - [thick film 0402/0603/0805/1206/1210/1812/2010/2512 series resistors](https://www.uni-royal.cn/en/product.php?id=19)

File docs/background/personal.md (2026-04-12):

# My Background

## My Education

After my parents divorced, my mom, my two sisters and I moved to [Santa Clara](https://en.wikipedia.org/wiki/Santa_Clara,_California) and my dad moved to [La Jolla](https://en.wikipedia.org/wiki/La_Jolla). It was the summer of my 7th birthday.

So, I had the luck of growing up in [Silicon Valley](https://en.wikipedia.org/wiki/Silicon_Valley) during the 1970s and early 1980s. In Silicon Valley, there were stores that sold used electronic parts and equipment. In addition, Radio Shack still existed and still sold electronic parts.

I had the further luck of spending three years in [John McCollum's electronics class](https://www.eetimes.com/john-mccollum-hs-teacher-taught-electronics-with-love/) at [Homestead High School](https://en.wikipedia.org/wiki/Homestead_High_School_(California)) (but fifteen years after Steve Wozniak and eleven years after Steve Jobs ... I'm not that old). Thanks to John McCollum, my interest in and understanding of electronics (especially digital electronics) grew.

After high school, I studied electrical engineering at [University of California San Diego (UCSD)](https://ucsd.edu). I completed a BS as well as a PhD. As an undergraduate student, I studied [communication theory and systems](https://www.ece.ucsd.edu/faculty-research/ece-research-areas/communication-theory-systems). As a graduate student, I studied [information theory](https://en.wikipedia.org/wiki/Information_theory) under [Jack Wolf](https://en.wikipedia.org/wiki/Jack_Wolf).

After college, I worked at [Qualcomm](https://www.qualcomm.com) as a systems engineer from 1992-2014. During my time there, I worked with and learned from many bright people, including [Andy Viterbi](https://en.wikipedia.org/wiki/Andrew_Viterbi), [Roberto Padovani](https://jacobsschool.ucsd.edu/people/profile/roberto-padovani),
Franklin Antonio, and of course [Irwin Jacobs](https://en.wikipedia.org/wiki/Irwin_M._Jacobs).

## My Interests

Generally, I like to figure out how things work and to learn new things. However, I'm most interested in electronics and home automation as well as in the software needed to make it work.

Apparently, I've always been interested in how things work. My mom says I would take things apart so that I could figure out how they worked. However, I couldn't put the thing back together some (most) of the time.

Since I was in elementary school, I have been interested in electronics. Of course I built a crystal radio set. Of course I tried to increase the range of my
[Walkie-Talkies](https://en.wikipedia.org/wiki/Walkie-talkie) by connecting them to an antenna on the roof. Of course I tried to automate light switches and electrical outlets, resulting in a few blown glass fuses.

And I loved building non-electronic things as well. My elementary school friend and I built multiple wooden forts at my house: one in the rafters of my garage, and more than one in the trees in my backyard. And I built things with [Lego](https://en.wikipedia.org/wiki/Lego). And I built things with [Erector Set](https://en.wikipedia.org/wiki/Erector_Set).

I loved taking shop classes.

In seventh grade at [Cabrillo Middle School](https://cabrillo.santaclarausd.org), I took metal shop and wood shop. I found out that I am afraid of power tools in general and circular saws in particular. To this day, I often do projects with the less than optimal tool because power tools make me nervous. I occasionally do projects involving wood, and the power drill and the jig saw still make me nervous. And I don't own a circular saw.

With the exception of shop classes, I was bored in middle school. I had already completed all the math material the middle school had to offer while I was in elementary school, and I found all the other subjects except shop boring. So I was often truant and sometimes in trouble. Through the efforts of my mom, I skipped eighth grade and started ninth grade at [Peterson High School](https://en.wikipedia.org/wiki/Peterson_High_School) where my mom taught.

In ninth grade, I took drafting. This was in 1979, which was before drafting was taught using a computer. I loved the precise drawings I could create with a drafting board, a t-square, a ruler, a triangle, a compass, a pencil and an eraser. It was in drafting class that I learned to print neatly. I still have my old-school drafting equipment, but rarely use it. I tend to do my architectural, mechanical and electrical drawing on a computer using purpose-built software such as [Home Designer Pro](https://www.homedesignersoftware.com/products/home-designer-pro/), [FreeCAD](https://www.freecad.org) and [KiCad](https://www.kicad.org).

In the summer after 9th grade, we moved from Santa Clara to Los Altos resulting in me changing from Peterson High School to [Homestead High School](https://en.wikipedia.org/wiki/Homestead_High_School_(California)). In addition to having access to more advanced math classes, I had access to more shop classes. I took auto shop and electronics, and I used the metal shop's equipment to help with building my electronics projects. Sadly, [my electronics teacher passed away in 1990](https://www.findagrave.com/memorial/58653313/john-claude-mccollum), and [the shop building was torn down in 2019](https://www.mercurynews.com/2019/10/05/homesteads-hub-is-a-place-for-collaboration/).

## My Digital Projects

### My First Digital Circuit (While a Homestead High School Student)

The first digital hardware I designed and built was a computer in 1982-1983 during my senior year of high school.

After spending my sophomore year learning about analog hardware and my junior year learning about digital hardware, my electronics class lab partner and I spent my senior year designing and building a computer. The computer's design was constrained by the parts our electronics teacher had acquired from various local companies Because the parts bin contained a [Z80A](https://en.wikipedia.org/wiki/Zilog_Z80) and numerous [7400 series ICs](https://en.wikipedia.org/wiki/7400-series_integrated_circuits), our initial design was similar to the [TRS-80](https://en.wikipedia.org/wiki/TRS-80). However, after finding a video display controller (VDC) in the parts bin (I don't remember the part but it could have been the [TMS9918A](https://en.wikipedia.org/wiki/TMS9918) based on its capabilities), we changed the design. The final design used the Z80A and the VDC, each with 16-kilobytes of RAM. The PCB was a hand-built, two layer board. We

- hand drew the schematic on paper,
- hand drew the layout on paper,
- transferred the layout to transparencies using a photocopier,
- transferred the layout to a copper clad board using photo-resist and sunlight,
- etched off the exposed copper using some sort of chemical bath,
- drilled the dual inline package (DIP) through holes using the metal shop's drill press, and
- hand soldered the components to the board.

### My Next Digital Project (While a UCSD Undergraduate Student)

The next digital hardware I designed was during the summer of 1987 as an intern at [NCR](https://www.ncr.com). It relied primarily on 7400 series ICs. However, I access to schematic capture, logic simulation and PCB layout software (anyone else remember [Daisy Systems](https://en.wikipedia.org/wiki/Daisy_Systems)). And after completing the PCB layout, I was able to have it auto-magically fabricated and assembled.

### My Last Digital Project (While a UCSD Graduate Student)

The last digital hardware I designed was during the 1989-1990 and 1990-1991 academic years as part of my PhD research. It was a board for quantifying the potential gains of using Reed-Solomon error correction codes on magnetic hard disk drives. Initially, the design used Advanced Hardware Architectures' AHA4010 Reed-Solomon ASICs (which were donated to us) along with numerous 7400 series ICs. The board was wire-wrapped by my sardonic, hard working, lab assistant. Unfortunately, it never ran at speed (30MHz) reliably. Thankfully, my advisor was willing to spend the money for the relatively costly Xilinx hardware and associated design software (anyone else remember FutureNet). The final design used two AHA4010 ASICs along with three Xilinx XC3042 FPGAs, was still wire-wrapped by my lab assistant, and ran at speed.

## My Other Projects

As a systems engineer at Qualcomm, I was more removed from the hardware and the software. I worked on the architectures and algorithms that the hardware and software would implement, but other people did the hardware and software designs and implementations.

And my personal projects became software centric:

- I wrote software to control my Lansonic DAS-750 networked MP3 player with my Compaq iPAQ PDA,
- I wrote software to control my Sony Plasma TV through its RS-232 serial port,
- I wrote software to assist my home church with projecting worship song lyrics,
- I maintained a Linux based distribution that turned diskless a VIA EPIA M based computer into MythTV frontend,
- I wrote software to make TV remote controls more plug and play under Linux,
- I wrote software to control my LG LCD TV through its websocket interface, and
- I contributed fixes to various Open Source software on which my home network and my software projects depended.

## My Life Phases

After completing my PhD, my life went through multiple phases:

1. I got married, I started working at Qualcomm and we bought the first home,
2. We had two boys, I took non-engineering assignments at Qualcomm, we sold the first home and we bought the second home,
3. I sufferend autistic burnout, I got mis-diagnosed with bipolar type 2, I got divorced and I was let go from Qualcomm,
4. I got married, we bought the third home and I continued to suffer from autistic burnout, and
5. the boys left home for college, I got officially diagnosed with autism and I recovered somewhat from the autistic burnout.

During the first phase, I had a lot of time to spend on personal projects, including home networking, home automation and Open Source software projects. During the second phase, I had less time to spend on personal projects. During the third phase, I lacked motivation to spend time personal projects. During the fourth phase, I still lacked motivation. During the fifth phase, I have had more time and more motivation to work on personal projects, including home networking, home automation and Open Source projects. During this time, I learned [Rust](https://rust-lang.org), I learned embedded develop on the ESP32 family using C on [esp-idf](https://docs.espressif.com/projects/esp-idf/en/stable/esp32/index.html) and Rust on [esp-hal](https://github.com/esp-rs/esp-hal)

During the first phase, the solutions were more DIY, partially because I had more time and partially because there were few/no turnkey options available. During the second, third and fourth phases, the solutions shifted toward more turnkey, partially because I had less time and partially because I had less motivation. During the fifth phase, the solutions have been a combination of turnkey and DIY.

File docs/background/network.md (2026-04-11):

# Our Networked Home

## Wired and Wireless Ethernet

Even though it was just the mid/late 1990s, it was obvious to me that distributing multimedia and home automation control in the home would be would be done over an IP network. [UCSD](https://www.ucsd.edu) where I attended university had been on the Internet while it was still the ARPANET. Qualcomm had been on the Internet since before I started there in 1992. So my believe everything would be carried over an IP network was natural.

Initially, our house relied on dial-up service to connect to the internet. Our phone lines were in bad shape so we regularly only got 9,600bps. So, when Time Warner Cable offered Internet connectivity we quickly switch from a dial-up modem to a cable modem.

In the late 1990s, I bought an [Aironet Wireless Communications](https://en.wikipedia.org/wiki/Aironet) AP4800 access point and PC4800 PCMCIA card. Being able to sit on my couch with my company-issued laptop and access the Internet was freeing.

I could do this before using the [cdmaOne (TIA/EIA/IS-95)](https://en.wikipedia.org/wiki/CdmaOne) and [1xEV-DO (TIA/EIA/IS-856)](https://en.wikipedia.org/wiki/Evolution-Data_Optimized) my company had been developing because the local cellular company offered cdmaOne async data and because my house was in the coverage area of our test 1xEV-DO network. However, compared to the the PC4800 PCMCIA card, the cdmaOne hardware and 1xEV-DO prototype hardware was bulky.

After buying and using the Aironet Wireless Communications wireless LAN devices, a few of us attempted to convince Qualcomm to develop 802.11 modems. However, after a rather limited effort, the project was canceled. Instead, Qualcomm purchased Airgo Networks in 2006 and Atheros Communications in 2011.

In 2001, I had my house wired with Category 5 UTP so that I could have wired Ethernet throughout the house. Some people thought I was crazy and told me I should either install more RJ6 coax or install fiber. I just told them that everything, including audio and video would be carried over IP soon and that residential IP would be transported by Ethernet over Cat 5/5e/6 UTP copper and Wi-Fi, not coax or fiber.

## Network Server

I had a server on the network. The server was computer running Red Hat Linux with hard-drives in a [RAID 1](https://en.wikipedia.org/wiki/Standard_RAID_levels#RAID_1) configuration. The network server performed various functions over the years, including

- a [DHCP server](https://www.isc.org/dhcp/),
- a [DNS server](https://www.isc.org/bind/),
- an [SMB file server](https://www.samba.org) for documents, audio and video,
- an [LDAP server](https://www.openldap.org),
- a [RADIUS server](https://www.freeradius.org),
- an [IMAP server](https://www.cyrusimap.org) including SPAM filtering,
- a [MisterHouse server](https://github.com/hollie/misterhouse/wiki),
- a [SlimServer (aka Squeezebox server)](https://wiki.lyrion.org/index.php/Squeezebox_Server.html)
- a [MythTV](https://www.mythtv.org) backend, and
- a [Minecraft server](https://www.minecraft.net/en-us/download/server)

## Migrating Away from DIY Solutions

By the late 2000s, work and my two wonderful boys were consuming more on my time. In addition, what has since been diagnosed as [autistic burnout](https://en.wikipedia.org/wiki/Autistic_burnout) was affecting my mental health. I no longer had the time and or the motivation to maintain my DIY network.

In 2010 we moved and I started simplifying the network.

- I didn't install any home automation hardware in the new house,
- I stopped working on MiniMyth in 2013,
- I stopped using LDAP for account management,
- I stopped using RADIUS for Wi-Fi access control,
- I migrated the DHCP, DNS, and SMB file server functions to a dedicated
[Synology&reg; DiskStation DS214play](https://global.download.synology.com/download/Document/Hardware/DataSheet/DiskStation/14-year/DS214play/enu/Synology_DS214play_Data_Sheet_enu.pdf),
- I started using
[Plex](https://www.plex.tv)
rather than MythTV for pictures, music, videos and DVDs, and
- I started using Roku along side my MiniMyth frontends.

In 2016, I moved again.

The inconvenient location of some light switches in the new house motivated a return to home automation.

- I started using the SmartThings Hub V2 as the center of my home automation,
- I started using Amazon Echos for voice control of devices exported by SmartThings and for music playback,
- I started using [Nuvyyo TabloTV](https://www.tablotv.com) rather than MythTV for recording television,
- I started using [Orbit B-Hyve](https://www.orbitonline.com/pages/b-hyve-the-smart-way-to-water) for irrigation control,
- I started using [Flume](https://flumewater.com) for tracking water usage in order monitor irrigation water usage and detect leaks (Flume has notified my a multiple dripping faucets, running toilets, irrigation leaks and a hot water pipe leak under the slab of the house. I believe, both water companies and insurance companies should provide a Flume to each of their customers.),
- I replaced the front door lock with a Schlage Connect Z-Wave Smart Deadbolt so that my wife and I would not have to take our house keys when we went on walks, and
- I replaced inconveniently located light switches with [Caséta by Lutron](https://www.casetawireless.com/us/en) light switches (the light switches in the house do not have neutral wires so my choice was limited.)

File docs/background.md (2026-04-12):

# Background

There have been multiple things that led me to this point.

As reflected in my [interests](./background/personal.md#my-interests), [educational choices](./background/personal.md#my-education) and projects ([digital](./background/personal.md#my-digital-projects) and [otherwise](./background/personal.md#my-other-projects)), I've always enjoyed designing and building things.

Since I was in high school, I've enjoyed [home automation](./background/automation.md). Not because home automation is useful, but because home automation is a problem to solve.

Since I graduated college, I've believed [as much as possible should be handled by my home IP network](./background/network.md).
I've believed this should include [home automation](./background/automation.md) and [multimedia](./background/multimedia.md).

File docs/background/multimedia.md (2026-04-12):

# Our Multimedia Home

## Migrating Away from Music CDs

In the mid 1980s, I migrated from vinyl to CDs.

In the late 1990s, I converted my CD collection to MP3s using [Exact Audio Copy](https://en.wikipedia.org/wiki/Exact_Audio_Copy). I burned MP3s to CD ROMs using
[Nero Burning ROM](https://en.wikipedia.org/wiki/Nero_Burning_ROM) so that I could listen to them at work and later my car. My car stereo had a CD player could read a CD ROM and could play MP3 files.

I purchased various portable MP3 players so that I could listen to them while running, including

- a [Creative Nomad MuVo2](https://en.wikipedia.org/wiki/Creative_Nomad),
- an [iRiver Prism](https://en.wikipedia.org/wiki/IRiver) (don't remember the model),
- a [SanDisk Sansa Clip](https://en.wikipedia.org/wiki/SanDisk_portable_media_players#Sansa_Clip), and
- a [SanDisk Sansa Clip+](https://en.wikipedia.org/wiki/SanDisk_portable_media_players#Sansa_Clip+).

I stayed with the SanDisk Sansa Clip+ until wireless charging came to the Apple iPhone and the Apple AirPods. The convenience of no headphone wires, the ease of wireless changing and the fact that my iPhone is always with me caused me to retire my SanDisk Sansa Clip+ and use my iPhone as my only portable MP3 player.

Once I had wired Ethernet throughout the house, I bought

- a [Lansonic DAS-750](https://web.archive.org/web/20001002044306/http://www.lansonic.com/product.htm),
- a [Slim Devices SLiMP3](https://wiki.lyrion.org/index.php/SLIMP3.html), and
- a [Logitech SqueezeBox 3](https://wiki.lyrion.org/index.php/Squeezebox_3rd_Generation.html)
- a [Logitech SqueezeBox Boom](https://lyrion.org/players-and-controllers/squeezebox-boom/)

so that I could listen to my MP3s on my family room stereo as well as in other rooms in the house.

Today, I listen to music using Amazon Alexa speaker connected Apple Music's streaming service because it is convenient. However, when I encounter music that I like enough, I buy the CD because I don't trust the longevity of any cloud-based service.

## Migrating Away from the VCR

In 2000, a few of us bought series 1 TiVos. Of course we added the Ethernet card that [Andrew Tridgell](https://en.wikipedia.org/wiki/Andrew_Tridgell)
(of [Samba](https://www.samba.org) fame) [developed](https://www.samba.org/~tridge/tivo-ethernet/). And of course we added multiple larger hard drives.

In 2005, I migrated from TiVo to [MythTV](https://www.mythtv.org) because MythTV fit with my belief that audio and video should be distributed over an IP network. MythTV has backends that are responsible for recording the cable and over-the-air television and frontends that are responsible for playing the content. In addition to being able to record and play back television, MythTV could flag and skip television commercials. In addition television recording and playback, it could display images, play music, play videos, play DVDs and play video games.

In 2005, I started helping Larry Matter with [MiniMyth](https://www.mythtv.org/wiki/Minimyth), eventually taking the lead on MiniMyth's development. I gravitated toward MiniMyth because it was a network bootable image that turned a relatively inexpensive diskless VIA EPIA M mini-ITX motherboard into a dedicated MythTV frontend.

When I moved in 2016, I stopped using MythTV because I didn't want to deal with maintaining the server required. I replaced MythTV's non-TV functions with
[Plex](https://www.plex.tv) running on my NAS. In 2020, I started using a [Nuvyyo Tablo QUAD 1TB DVR](https://www.engadget.com/tablo-dual-128gb-quad-1tb-announcement-211652423.html) for TV functions.

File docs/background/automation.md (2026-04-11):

# Our Automated Home

## Home Assistant

Currently, [Home Assistant](https://www.home-assistant.io) is at the center of our home automation system.

## Before Home Assistant there was SmartThings

Before switching to Home Assistant, [SmartThings](https://en.wikipedia.org/wiki/SmartThings) was at the center of my home automation system. I liked SmartThings because

- the SmartThings hub supported local control over Zigbee, Z-Wave and IP,
- SmartThings supported a wide selection of locally controllable automation hardware,
- SmartThings supported a wide selection of cloud controllable automation hardware for when there wasn't a reliable locally controllable alternative,
- SmartThing encouraged people to write and distribute custom SmartThings software.

However, after SmartThings acquisition by Samsung, SmartThings changed how software is written and appeared to shift its focus to cloud based functionality. So, I migrated to Home Assistant.

For a while I kept my SmartThings cloud account and SmartThings hub around because of my [Aladdin Connect&reg;](https://www.geniecompany.com/aladdin-connect-/aladdin-connect) Wi-Fi Retrofit Kit from Genie and my [Schlage Connect&trade;](https://www.schlage.com/en/home/products/smart-deadbolts-levers.html#tab-item-0d633d3781-tab) smart deadbolt from Schlage.

### Fixing My Genie Aladdin Connect by Replacing It with ratgdo32

I had been using a Genie Aladdin Connect retrofit kit to connector our two Genie garage door openers to our home automation system. Unfortunately, Genie Aladdin Connect uses the cloud. Some time ago, Genie decided to make incompatible changes the Aladdin Connect cloud API and to release a Aladdin Connect cloud API SDK for the changed API under an OSI incompatible license. Therefore, until either Genie releases the SDK (or the API) under an OSI compatible license or someone who has not been tainted by the SDK successfully reverse engineers the API, it appears Home Assistant will not be able to use the Genie Aladdin Connect cloud API to integrate with Aladdin Connect.

Genie promised to resolve the issue with connecting Home Assistant to the Aladdin Connect cloud. As a stop-gap until Genie made good on their promise, I paired my Genie Aladdin Connect cloud account with my SmartThings cloud account so that SmartThings cloud could control my garage doors though the Genie Aladdin cloud. Then I paired my SmartThings cloud account with my local Home Assistant so that Home Assistant could control my garage doors.

However, after months of apparent inactivity it became clear to me that Genie was unlikely to come through on their promise. This gave me the motivation to look for an open and cloud-free replacement for Genie Aladdin Connect. While I found multiple DIY and non-DIY solutions that would likely have worked, I settled on
[ratgdo32](https://ratcloud.llc/pages/about) because it appeared that it would meet my needs and it allowed me to support someone whose work is helping to make possible home automation that is both open and cloud-free. After some months, I can say that I prefer the ratgdo32 to the Aladdin Connect retrofit kit because

- ratgdo32's Home Assistant integration has been more responsive than Aladdin Connect's Home Assistant integration had been, likely because the Aladdin Connect uses the cloud, and
- ratgdo32's door status information has been more reliable than Aladdin Connect's door status information had been, likely because the Aladdin Connect retrofit kit relies on a wireless tilt sensor to determine the door status whereas ratgdo32 relies on my garage door's open and close limit switches.

Genie has provided a textbook example of why requiring the cloud for a device to provide a local service is never in the customer's best interest. I purchased the Genie Aladdin Connect retrofit kit so that I could integrate my Genie garage door openers with my home automation system. When I purchased the kit, it worked with home automation system through the Aladdin Connect cloud. After I purchased the kit, Genie decided to make incompatible changes to cloud API as well as release the SDK for the new cloud API under an OSI incompatible license. Essentially, Genie decided to force changes that broke the Genie Aladdin Connect retrofit kit. They did so without compensating me of the harm they did to me. The did so without giving me no way to reject the changes and maintain the current functionality.

This is another example of why we should stop buying devices that require a cloud. This is another example of why we should pass laws that make it illegal for companies to make cloud changes that cause a loss of functionality to unless they provide owners a full refund. If they want to run some of the software for the hardware they sell in a cloud, then they should be required to run the cloud in a manner that never reduces the functionality of hardware they have sold.

### Fixing My Schlage Connect Smart Deadbolt By Waiting

Home Assistant in combination with the [Zooz Z-Wave 800 Long Range USB stick (ZST39)](https://www.getzooz.com/zooz-zst39-z-wave-long-range-usb-stick/) drained the batteries in my Schlage Connect smart deadbolt in under a few weeks. As a result, I paired the lock with my SmartThings hub instead. Then I paired my SmartThings cloud account with my local Home Assistant so that Home Assistant could control the lock.

Because removing the lock from one Z-Wave network and adding it to another is somewhat of a hassle, I did not test the lock with each new ZST39 firmware update much less with each Home Assistant Z-Wave update. However, as of [ZST39 firmware v1.50 (SDK v7.22.1)](https://www.support.getzooz.com/kb/article/1352-zst39-800-long-range-z-wave-stick-change-log/), connecting the lock to Home Assistant using the ZST39 no longer drains the lock's battery.

With those two problems solved, I retired my SmartThings hub and my SmartThings cloud account.

## Before SmartThings there was MisterHouse

Before switching to SmartThings, I used [MisterHouse](https://github.com/hollie/misterhouse/wiki). I replaced MisterHouse with SmartThings because I was finding less time to tinker with projects so a turnkey solution was more appealing, and because we moved to a new house so existing configuration was not an issue.

MisterHouse controlled

- my X10 devices
- my plasma TV, and
- my irrigation system.

I wrote software to control the TV through its RS-232 port. There was really no reason to control the TV through its serial port other than the fact that I could control the TV through its serial port. Controlling home hardware through a serial port has been a recurring theme as serial ports are prevalent.

I bought the irrigation controller over the Internet. It was a black metal box with an Ethernet connection and relays for controlling the irrigation valves. It lacked any local control but since I was the only one using the irrigation controller, that was not a problem.

## Before MisterHouse there was X10

Before switching to MisterHouse, the only smart home hardware I used was [X10](https://en.wikipedia.org/wiki/X10_(industry_standard)). It worked most of them and it was relatively affordable.

However, this was before wired and wireless ethernet took over my house.

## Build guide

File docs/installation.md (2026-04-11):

# Wireless Adapter Installation

## Load with ESPHome

Once the ESPHome image is compiled, load it using the USB-C connector.

## Connect to Indoor Unit and Wireless Receiver

Remove power from the indoor unit (typically be removing power from the outdoor unit).

Remove the indoor unit's panel in order to access the CN105 connector. For my indoor units, instructions for removing the panel can be found in section "10. Disassembly Instructions" of the [Service Manual for the MSZ-GLxxNA and MSY-GLxxNA Indoor Units](https://www.mitsubishitechinfo.ca/sites/default/files/SH_MS%28Y%29%28Z%29-GL09_24NA_OBH732D.pdf).

If connected, unplug the wireless receiver from the indoor unit's CN105 connector

Attach the enclosure bottom to the wall with drywall anchors.

Connect the indoor unit's CN105 connector to the wireless adapter's IU connecter. For this, a cable is needed. I chose a [50cm, same direction, PAP-05V-S cable](https://www.aliexpress.us/item/3256810525305677.html). I found that a [20cm, same direction, PAP-05V-S cable](https://www.aliexpress.us/item/3256804560686405.html) was too short.

If present, connect the wireless receiver cable to the wireless adapter's WR connector.

Attach the PCBA to the enclosure bottom using four white nylon, 10mm long M3 standoffs.

Attach the enclosure top to the enclosure bottom using four white nylon, 15mm long, flat countersunk head M3 screws.

Replace the indoor unit's panel.

Apply power to the indoor unit.

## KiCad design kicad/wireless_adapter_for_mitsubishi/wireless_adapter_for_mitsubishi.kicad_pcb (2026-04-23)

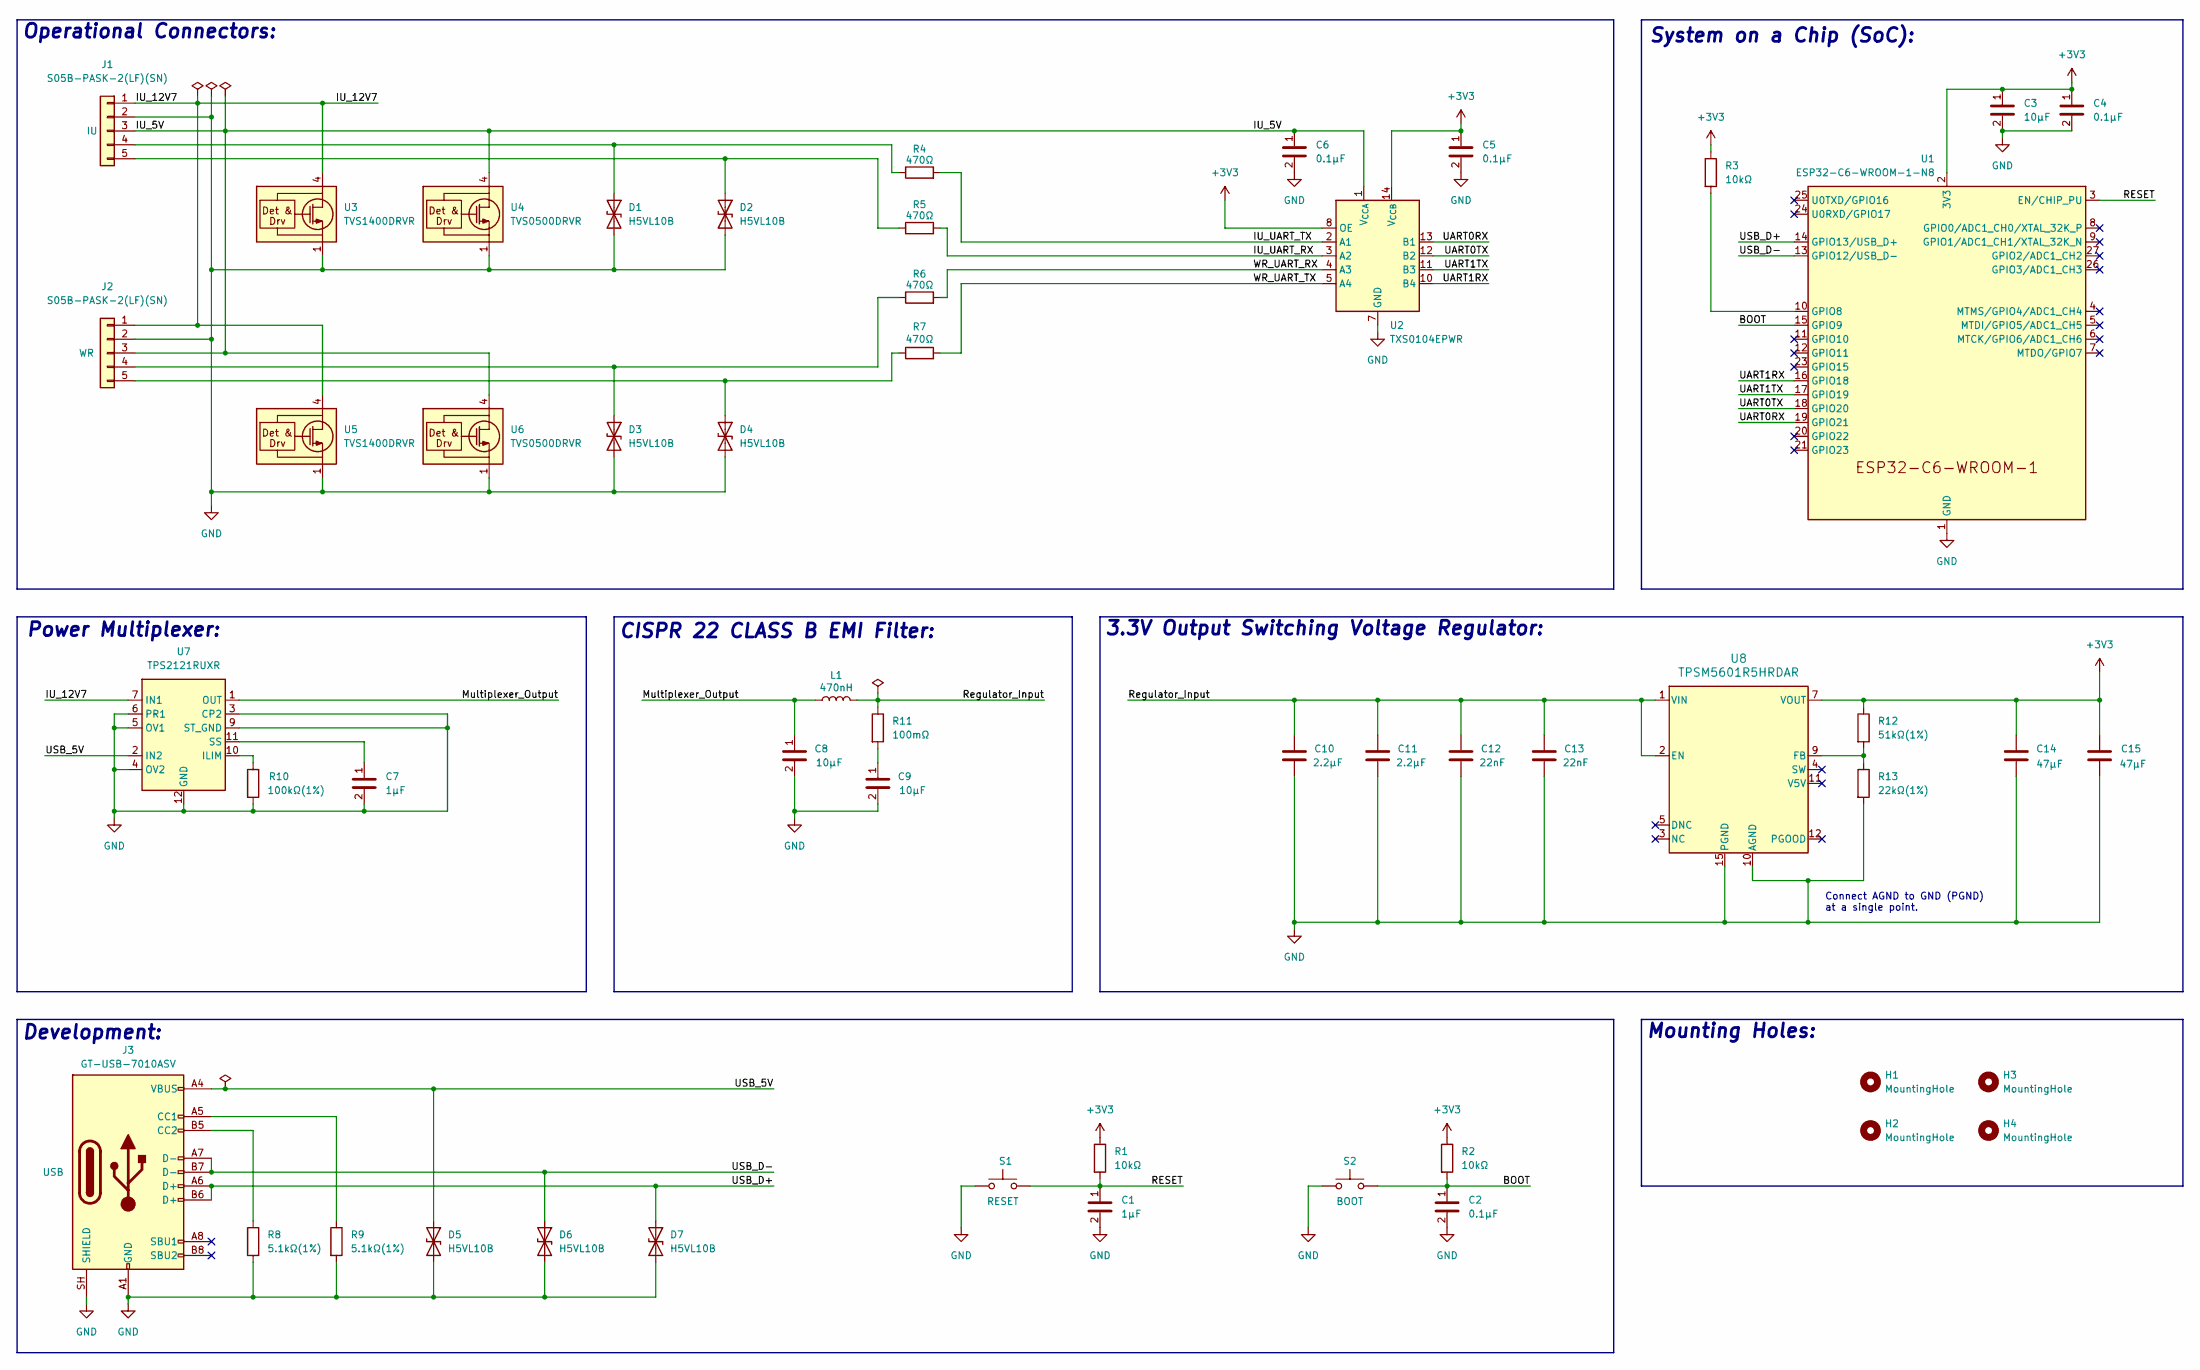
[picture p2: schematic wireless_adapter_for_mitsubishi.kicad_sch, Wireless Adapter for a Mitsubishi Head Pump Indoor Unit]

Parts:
C1, C7: 1μF; C_0402_1005Metric; Part CL05A105KA5NQNC; LCSC Part # C52923
C2, C4, C5, C6: 0.1μF; C_0402_1005Metric; Part CL05B104KO5NNNC; LCSC Part # C1525
C3, C8, C9: 10μF; C_1206_3216Metric; Part CL31A106KBHNNNE; LCSC Part # C13585
C10, C11: 2.2μF; C_1206_3216Metric; Part CL31B225KBHNNNE; LCSC Part # C50254
C12, C13: 22nF; C_0603_1608Metric; Part CL10B223KB8NNNC; LCSC Part # C21122
C14, C15: 47μF; C_1206_3216Metric; Part CL31A476MPHNNNE; LCSC Part # C96123
D1, D2, D3, D4, D5, D6, D7: H5VL10B; D_SOD-882; Part H5VL10B; LCSC Part # C7420372
H1, H2, H3, H4: MountingHole; MountingHole_3.2mm_M3
J1, J2: S05B-PASK-2(LF)(SN); JST_PA_S05B-PASK-2_1x05_P2.00mm_Horizontal; Part S05B-PASK-2(LF)(SN); LCSC Part # C489718
J3: GT-USB-7010ASV; USB_C_Receptacle_G-Switch_GT-USB-7010ASV; Part GT-USB-7010ASV; LCSC Part # C2988369
L1: 470nH; L_0806_2016Metric; Part DFE201610E-R47M=P2; LCSC Part # C269773
R1, R2, R3: 10kΩ; R_0402_1005Metric; Part 0402WGF1002TCE; LCSC Part # C25744
R4, R5, R6, R7: 470Ω; R_0402_1005Metric; Part 0402WGF4700TCE; LCSC Part # C25117
R8, R9: 5.1kΩ(1%); R_0402_1005Metric; Part 0402WGF4700TCE; LCSC Part # C25117
R10: 100kΩ(1%); R_0402_1005Metric; Part 0402WGF1003TCE; LCSC Part # C25741
R11: 100mΩ; R_1206_3216Metric; Part 1206W4F100LT5E; LCSC Part # C25334
R12: 51kΩ(1%); R_0402_1005Metric; Part 0402WGF5102TCE; LCSC Part # C25794
R13: 22kΩ(1%); R_0402_1005Metric; Part 0402WGF2202TCE; LCSC Part # C25768
S1, S2: SW_PUSH; SW_SPST_TS-1088-xR020; Part TS-1088-AR02016; LCSC Part # C720477
U1: ESP32-C6-WROOM-1-N8; ESP32-C6-WROOM-1; LCSC Part # C5366877
U2: TXS0104EPWR; TSSOP-14_4.4x5mm_P0.65mm; Part TXS0104EPWR; LCSC Part # C44955
U3, U5: TVS1400DRVR; WSON-6-1EP_2x2mm_P0.65mm_EP1x1.6mm; Part TVS1400DRVR; LCSC Part # C1975229
U4, U6: TVS0500DRVR; WSON-6-1EP_2x2mm_P0.65mm_EP1x1.6mm; Part TVS0500DRVR; LCSC Part # C609571
U7: TPS2121RUXR; Texas_RUX0012A_VQFN-HR-12_2x2.5x1mm_P0.5mm; Part TPS2121RUXT; LCSC Part # C2156025
U8: TPSM5601R5HRDAR; Texas_RDA0015A_B3QFN-14-1EP_5x5.5x4.1mm_P0.65mm; Part TPSM5601R5HRDAR; LCSC Part # C2846044

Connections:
+3V3: C3.1, C4.1, C5.1, C14.1, C15.1, R1.1, R2.1, R3.1, R12.1, U1.2 (3V3), U2.8 (OE), U2.14 (V_{CCB}), U8.7 (VOUT), U8.8 (VOUT)
/BOOT: C2.1, R2.2, S2.2, U1.15 (GPIO9)
/IU_5V: C6.1, J1.3, J2.3, U2.1 (V_{CCA}), U4.4 (IN), U4.5 (IN), U4.6 (IN), U6.4 (IN), U6.5 (IN), U6.6 (IN)
/IU_12V7: J1.1, J2.1, U3.4 (IN), U3.5 (IN), U3.6 (IN), U5.4 (IN), U5.5 (IN), U5.6 (IN), U7.7 (IN1)
/IU_UART_RX: R5.2, U2.3 (A2)
/IU_UART_TX: R4.2, U2.2 (A1)
/Multiplexer_Output: C8.1, L1.1, U7.1 (OUT), U7.8 (OUT)
/RESET: C1.1, R1.2, S1.2, U1.3 (EN/CHIP_PU)
/Regulator_Input: C10.1, C11.1, C12.1, C13.1, L1.2, R11.1, U8.1 (VIN), U8.2 (EN), U8.14 (VIN)
/UART0RX: U1.19 (GPIO21), U2.13 (B1)
/UART0TX: U1.18 (GPIO20), U2.12 (B2)
/UART1RX: U1.16 (GPIO18), U2.10 (B4)
/UART1TX: U1.17 (GPIO19), U2.11 (B3)
/USB_5V: D5.1 (A1), J3.A4 (VBUS), J3.A9 (VBUS), J3.B4 (VBUS), J3.B9 (VBUS), U7.2 (IN2)
/USB_D+: D7.1 (A1), J3.A6 (D+), J3.B6 (D+), U1.14 (GPIO13/USB_D+)
/USB_D-: D6.1 (A1), J3.A7 (D-), J3.B7 (D-), U1.13 (GPIO12/USB_D-)
/WR_UART_RX: R6.2, U2.4 (A3)
/WR_UART_TX: R7.2, U2.5 (A4)
GND: C1.2, C2.2, C3.2, C4.2, C5.2, C6.2, C7.2, C8.2, C9.2, C10.2, C11.2, C12.2, C13.2, C14.2, C15.2, D1.2 (A2), D2.2 (A2), D3.2 (A2), D4.2 (A2), D5.2 (A2), D6.2 (A2), D7.2 (A2), J1.2, J2.2, J3.A1 (GND), J3.A12 (GND), J3.B1 (GND), J3.B12 (GND), J3.SH (SHIELD), R8.2, R9.2, R10.2, R13.2, S1.1, S2.1, U1.1 (GND), U1.28 (GND), U1.29 (GND), U2.7 (GND), U3.1 (GND), U3.2 (GND), U3.3 (GND), U3.7 (GND), U4.1 (GND), U4.2 (GND), U4.3 (GND), U4.7 (GND), U5.1 (GND), U5.2 (GND), U5.3 (GND), U5.7 (GND), U6.1 (GND), U6.2 (GND), U6.3 (GND), U6.7 (GND), U7.3 (CP2), U7.4 (OV2), U7.5 (OV1), U7.6 (PR1), U7.9 (ST_GND), U7.12 (GND), U8.10 (AGND), U8.15 (PGND)
unnamed: C9.1, R11.2
unnamed: D1.1 (A1), J1.4, R4.1
unnamed: D2.1 (A1), J1.5, R5.1
unnamed: D3.1 (A1), J2.4, R6.1
unnamed: D4.1 (A1), J2.5, R7.1
unnamed: J3.A5 (CC1), R9.1
unnamed: J3.B5 (CC2), R8.1
unnamed: R3.2, U1.10 (GPIO8)
unnamed: R10.1, U7.10 (ILIM)
unnamed: C7.1, U7.11 (SS)
unnamed: R12.2, R13.1, U8.9 (FB)

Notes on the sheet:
Connect AGND to GND (PGND) at a single point.
System on a Chip (SoC):
Mounting Holes:
Operational Connectors:
3.3V Output Switching Voltage Regulator:
CISPR 22 CLASS B EMI Filter:
Power Multiplexer:
Development:

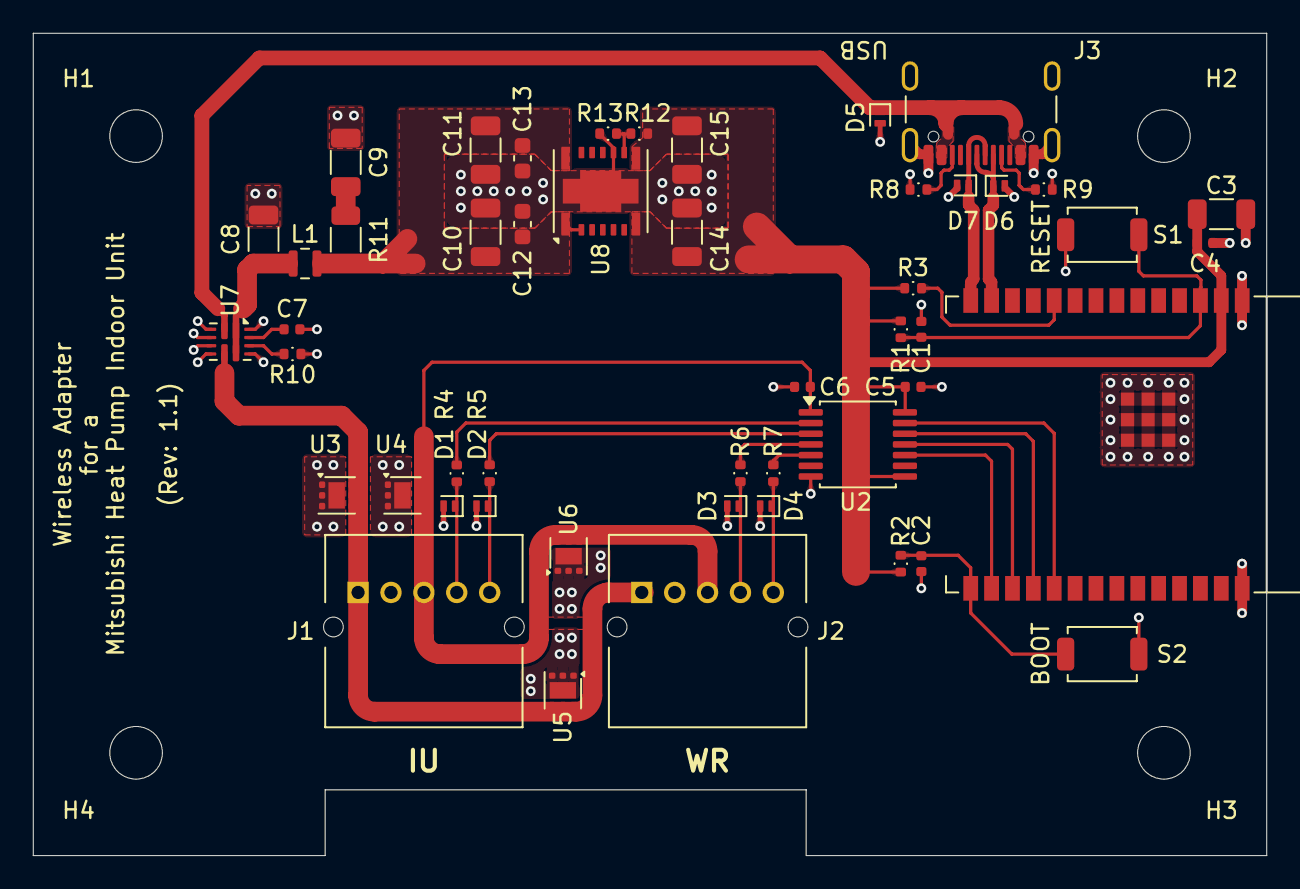
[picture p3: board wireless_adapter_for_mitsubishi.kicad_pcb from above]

Board: 2 copper layers, 75.0 x 50.0 mm, 53 parts (0 on the bottom side), 30 nets.

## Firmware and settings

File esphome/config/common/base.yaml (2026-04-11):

esphome:
  name: ${name}
  friendly_name: ${friendly_name}
  min_version: 2026.3.3

  on_boot:
    priority: 260
    then:
      - select.set:
          id: temperature_source_select
          option: "Thermostat"

esp32:
  variant: esp32c6
  flash_size: 8MB
  framework:
    type: esp-idf

external_components:
  - source: github://muart-group/esphome-components@dev
    components: [ mitsubishi_itp ]

ota:
  - platform: esphome
    password: ${ota_password}

api:
  encryption:
    key: ${api_encryption_key}

globals:
  - id: m_ctof_c
    type: float[157]
    initial_value: |-
      {-18,
      -17.5,
      -17,
      -16.5,
      -16,
      -15.5,
      -15,
      -14.5,
      -14,
      -13.5,
      -13,
      -12.5,
      -12,
      -11.5,
      -11,
      -10.5,
      -10,
      -9.5,
      -9,
      -8.5,
      -8,
      -7.5,
      -7,
      -6.5,
      -6,
      -5.5,
      -5,
      -4.5,
      -4,
      -3.5,
      -3,
      -2.5,
      -2,
      -1.5,
      -1,
      -0.5,
      0,
      0.5,
      1,
      1.5,
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
  - id: m_ctof_f
    type: float[157]
    initial_value: |-
      {0,
      1,
      1,
      2,
      3,
      4,
      5,
      6,
      7,
      8,
      9,
      10,
      10,
      11,
      12,
      13,
      14,
      15,
      16,
      17,
      18,
      19,
      19,
      20,
      21,
      22,
      23,
      24,
      25,
      26,
      27,
      28,
      28,
      29,
      30,
      31,
      32,
      33,
      34,
      35,
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

time:
  - platform: homeassistant
    id: homeassistant_time

uart:
  - id: iu_uart
    baud_rate: 2400
    parity: EVEN
    rx_pin: GPIO21
    tx_pin: GPIO20
  - id: wr_uart
    baud_rate: 2400
    parity: EVEN
    rx_pin: GPIO18
    tx_pin: GPIO19

climate:
  - platform: mitsubishi_itp
    id: heat_pump
    name: "Thermostat"
    icon: mdi:heat-pump
    uart_heatpump: iu_uart
    uart_thermostat: wr_uart
    supported_modes:
      - 'OFF'
      - HEAT
      - COOL
      - FAN_ONLY
      - DRY
    supported_fan_modes:
      - AUTO
      - QUIET
      - LOW
      - MEDIUM
      - HIGH
    custom_fan_modes:
      - VERYHIGH
    # enhanced_mhk: True
    visual:
      temperature_step:
        target_temperature: 1.0
        current_temperature: 1.0
    update_interval: 10s
    on_state:
      - lambda: |-
          float target_temperature = id(heat_pump).target_temperature;
          for (int i = 0; i < sizeof(id(m_ctof_c))/sizeof(id(m_ctof_c)[0]); i++) {
            if (id(m_ctof_c)[i] == target_temperature) {
              ESP_LOGD("on_state", "target_temperature=%f", target_temperature);
              id(heat_pump).target_temperature = (id(m_ctof_f)[i] - 32.0) * 5.0 / 9.0;
              ESP_LOGD("on_state", "target_temperature=%f", id(heat_pump).target_temperature);
            }
          }
          float current_temperature = id(heat_pump).current_temperature;
          for (int i = 0; i < sizeof(id(m_ctof_c))/sizeof(id(m_ctof_c)[0]); i++) {
            if (id(m_ctof_c)[i] == current_temperature) {
              ESP_LOGD("on_state", "current_temperature=%f", current_temperature);
              ESP_LOGD("on_state", "current_temperature=%f", id(heat_pump).current_temperature);
            }
          }
    on_control:
      - lambda: |-
          float target_temperature_c = id(heat_pump).target_temperature;
          float target_temperature_f = round(target_temperature_c * 9.0 / 5.0 + 32.0);
          for (int i = 0; i < sizeof(id(m_ctof_f))/sizeof(id(m_ctof_f)[0]); i++) {
            if (id(m_ctof_f)[i] == target_temperature_f) {
              ESP_LOGD("on_control", "target_temperature=%f", target_temperature_c);
              id(heat_pump).target_temperature = (id(m_ctof_f)[i] - 32.0) * 5.0 / 9.0;
              ESP_LOGD("on_control", "target_temperature=%f", id(heat_pump).target_temperature);
            }
          }

select:
  - platform: mitsubishi_itp
    temperature_source:
      name: "Temperature Source"
      id: temperature_source_select
      sources: []
    vane_position:
      name: "Vane Position"
    horizontal_vane_position:
      name: "H. Vane Position"

text_sensor:
  - platform: mitsubishi_itp
    actual_fan:
      name: "Actual Fan"
    error_code:
      name: "Error Code"

# Default logging level
logger:
  baud_rate: 0
  level: DEBUG
  logs:
    EVT_SETS : DEBUG
    WIFI : INFO
    MQTT : INFO
    WRITE_SETTINGS : DEBUG
    SETTINGS : DEBUG
    STATUS : INFO
    CN105Climate: WARN
    CN105: DEBUG
    climate: WARN
    sensor: WARN
    chkSum : INFO
    WRITE : WARN
    READ : WARN
    Header: INFO
    Decoder : DEBUG
    CONTROL_WANTED_SETTINGS: DEBUG

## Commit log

2026-04-13 Rename some of the KiCad sheets.
    [connector_iu.kicad_sch, connector_usb.kicad_sch, connector_wr.kicad_sch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]
2026-04-13 Fix the name of a KiCad sheet.
    [wireless_adapter_for_mitsubishi.kicad_pcb, wireless_adapter_for_mitsubishi.kicad_sch]
2026-04-13 Rename some KiCad buses.
    [connector_iu.kicad_sch, connector_wr.kicad_sch, wireless_adapter_for_mitsubishi.kicad_pcb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]
2026-04-14 Clean up KiCad schematic.
    [connector_iu.kicad_sch, connector_usb.kicad_sch, connector_wr.kicad_sch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]
2026-04-15 Flatten KiCad schematic.
    [connector_iu.kicad_sch, connector_usb.kicad_sch, connector_wr.kicad_sch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]
2026-04-17 Update PCBA STEP file.
2026-04-20 Clean up KiCad schematic. Improve grounding in on PCB.
    [wireless_adapter_for_mitsubishi.kicad_pcb, wireless_adapter_for_mitsubishi.kicad_sch]
2026-04-23 Improve USB differential routing.
    [wireless_adapter_for_mitsubishi.kicad_pcb]
2026-05-05 Fix problem with thread support.
2026-05-21 Switch to using main branch of muart.
2026-07-19 Switch to the v1 branch.
2026-07-21 Switched to using mhk_fahrenheit_correction
2026-10-23 Switch muart to main branch.
